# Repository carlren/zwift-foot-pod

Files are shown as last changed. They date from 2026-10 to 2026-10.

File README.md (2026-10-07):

# Carl Foot Pod

A battery-powered foot pod built around the **Seeed XIAO nRF52840 Sense**.
It estimates walking cadence from the on-board gyroscope and publishes it directly
to **Zwift over Bluetooth**. **Foot Pod Lab** on Android previews the six-axis IMU,
records sessions for algorithm development, and reads the pod’s battery voltage
and estimated charge level.

**Firmware:** 0.4.0 · **Android app:** 1.0.1 · **BLE name:** `Carl Foot Pod` · **Software license:** [MIT](LICENSE)

<p>
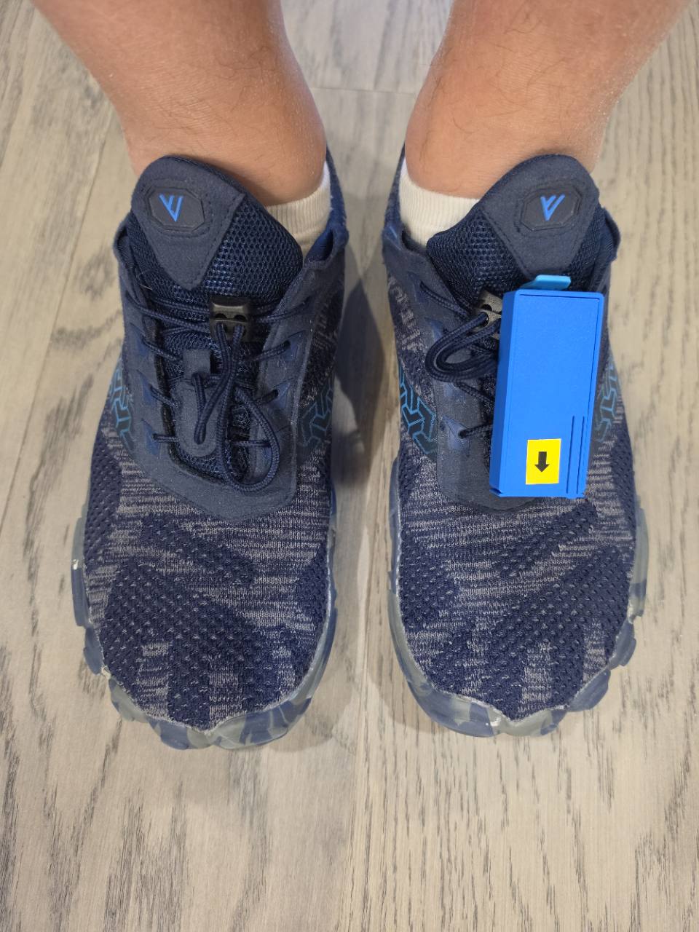
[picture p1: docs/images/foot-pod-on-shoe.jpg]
Blue foot pod case clipped to a shoe’s laces, with its orientation arrow pointing toward the toe
  
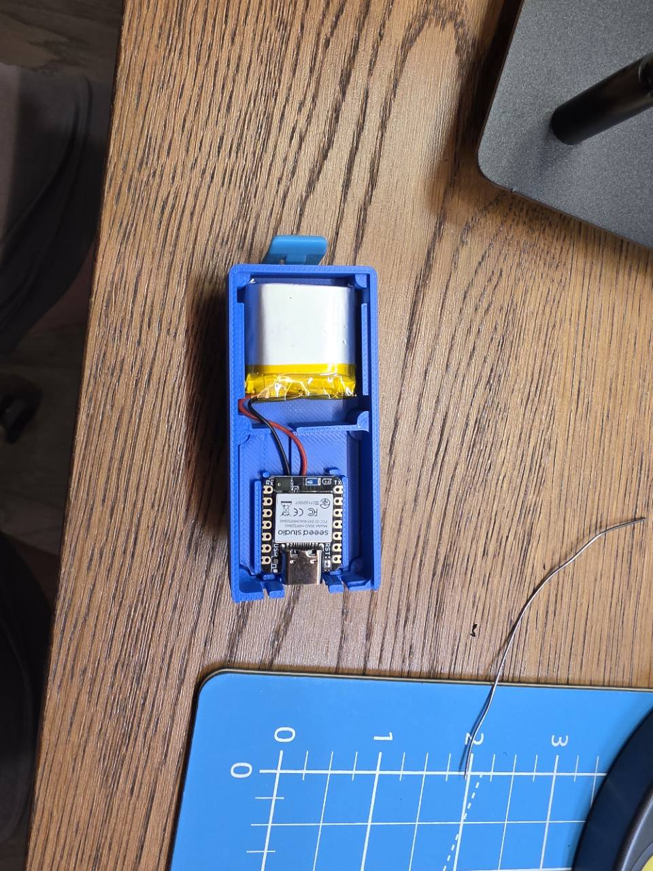
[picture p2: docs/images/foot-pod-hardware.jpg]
Open blue case containing a LiPo pouch battery and the Seeed XIAO board with battery leads attached
  
</p>

The assembled pod clips over the shoelaces. Inside the blue case are the XIAO
board and a pouch battery. The yellow arrow marks the mounting orientation used
for this setup; keep the sensor orientation consistent when comparing recordings.

## Mounting and walking-desk setup

<p>
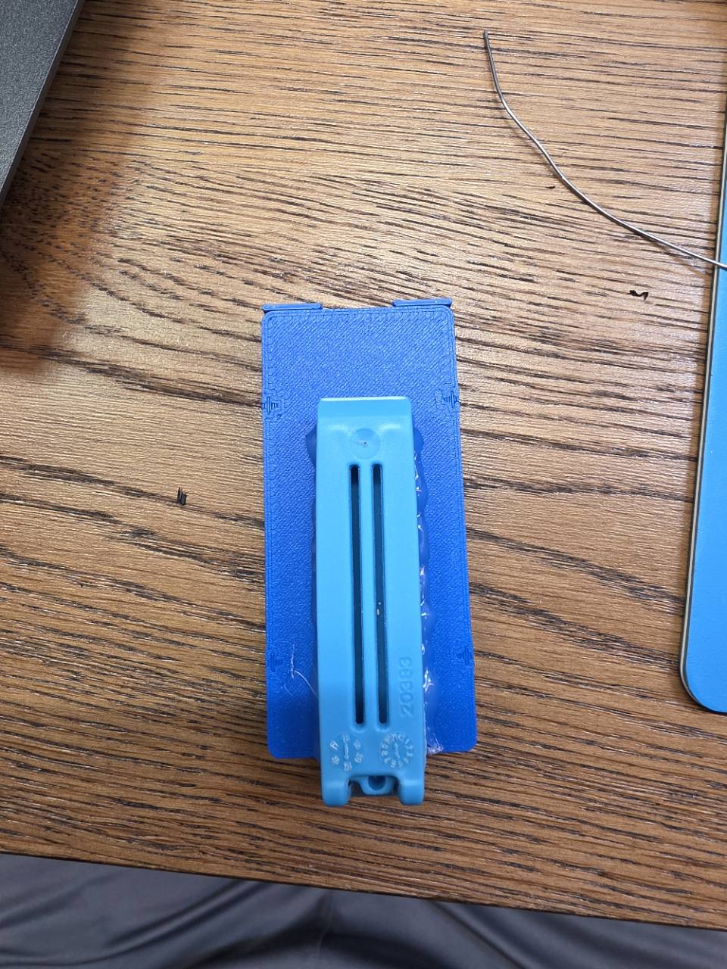
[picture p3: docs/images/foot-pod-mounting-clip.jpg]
Rear of the blue foot pod case showing the long turquoise mounting clip attached to the back
  
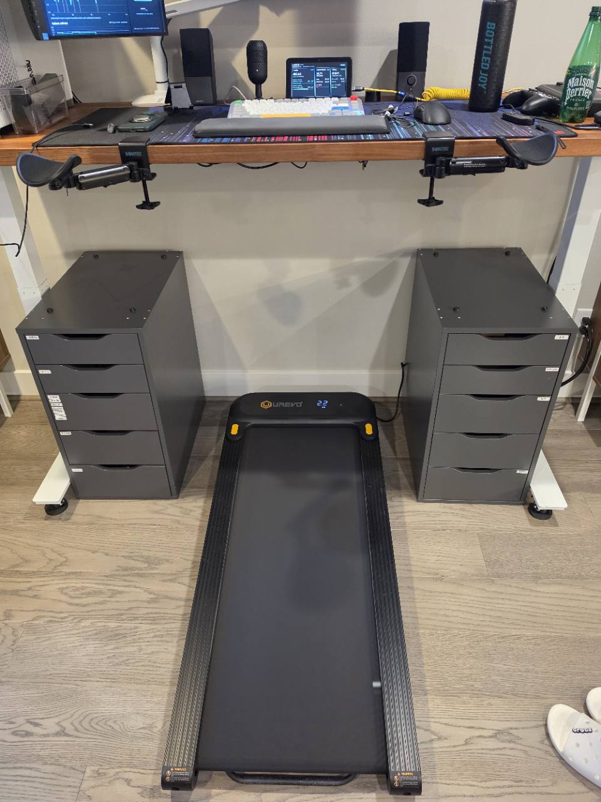
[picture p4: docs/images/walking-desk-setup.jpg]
UREVO walking pad beneath a standing desk with keyboard, displays and front-mounted arm supports
  
</p>

The rear view shows the long mounting clip attached to the case, complementing
the photo of the pod on the shoelaces above. Secure the case so it stays in the
same orientation during walking and recording.

The second photo shows the walking pad under the standing desk, with displays,
a keyboard and arm supports. This is the physical setup used alongside the shoe
pod, Zwift and the phone companion.

The [V5 enclosure design](enclosure/README.md) is now included: printable STLs,
editable STEP/CadQuery files, previews and the original print/assembly guide.
Download the [exact enclosure package](enclosure/low-profile-v5-package.zip) or
browse the [individual parts](enclosure/low-profile-v5/).

## What it does

- Computes cadence on the pod, without a computer or phone relay, and publishes
  Running Speed and Cadence (RSC) notifications once per second.
- Supports two BLE central connections so Zwift and a companion on another device
  can connect. Starting or stopping the companion’s IMU stream leaves cadence publishing active.
- Streams timestamped gyro X/Y/Z and accelerometer X/Y/Z samples at roughly 104 Hz.
- Separates **Connect** for live preview from **Record** for saving a new session.
- Shows battery voltage and an estimated percentage, including a dedicated battery
  bar with charging status and low-battery colors.
- Saves raw IMU data, gyro fit results and reference annotations; retains partial
  captures if recording ends unexpectedly.

Use this pod as a **cadence source**. The speed field required by RSC currently
uses a placeholder 0.70 m step length. Keep the treadmill or another measured
speed source under Zwift’s **RUN SPEED**.

## Parts and purchase links

| Part | Quantity | Purchase / source |
| --- | --- | --- |
| Seeed XIAO nRF52840 Sense | 1 | [Amazon — original board purchase link](https://a.co/d/03LYRqK2) · [Direct listing](https://www.amazon.com/dp/B0DJ6PZGB7) |
| LiPo pouch battery | 1 | The V5 design uses a measured **26.31 × 25.07 × 8.66 mm** cell; the exact purchased battery listing has not been supplied. |
| Housing, sliding cover, board carrier, adapter and lace base | 1 set | [Printable enclosure parts](enclosure/README.md#print-files) · [Complete design ZIP](enclosure/low-profile-v5-package.zip) |
| PLA or PETG filament | As needed | Materials specified in the [print and assembly guide](enclosure/low-profile-v5/PRINT-AND-ASSEMBLE.md#printing). |
| Thin battery mounting tape and CA glue | As needed | The design allows **0.20 mm** tape under the battery and uses CA glue for the adapter; see [assembly instructions](enclosure/low-profile-v5/PRINT-AND-ASSEMBLE.md#assembly-and-use). |

Select the **original Sense model with the on-board IMU** for the firmware and
board carrier in this repository. The Amazon link above is the board link Carl
provided when buying this project's hardware. Battery selection must match the
cell dimensions and clearances in the enclosure design; no unverified battery
product link is presented as the one used here.

## Get the firmware and app

| Component | Download / source |
| --- | --- |
| V5 enclosure | [Original package](enclosure/low-profile-v5-package.zip) · [Design and print guide](enclosure/README.md) |
| Firmware 0.4.0 | [GitHub release, DFU package, HEX and validation](https://github.com/carlren/zwift-foot-pod/releases/tag/v0.4.0) |
| Android app 1.0.1 | [GitHub APK release](https://github.com/carlren/zwift-foot-pod/releases/tag/android-v1.0.1) · [APK on Google Drive](https://drive.google.com/file/d/1NDdZ-bwayQZ8dlKcvDCeHdjqc7yNuZNr/view?usp=drivesdk) |
| Android source and instructions | [android/README.md](android/README.md) |
| Desktop collection, build and protocol details | [Development guide](docs/development.md) |

The repository and its GitHub release downloads are private. The releases are
marked prerelease while broader mounting, gait, runtime and simultaneous-device
stress testing remain unfinished. Firmware 0.3.0 and Android 1.0.0 remain in the
release history.

## Pair with Zwift

1. Power the pod and keep it mounted in the same orientation used for calibration.
2. Open Zwift’s **RUN** pairing screen.
3. Select **Carl Foot Pod** under **CADENCE**.
4. Keep the treadmill or other speed source under **RUN SPEED**.
5. Allow a few walking strides for the cadence estimate to settle. Standing still
   returns cadence to zero after the stop timeout.

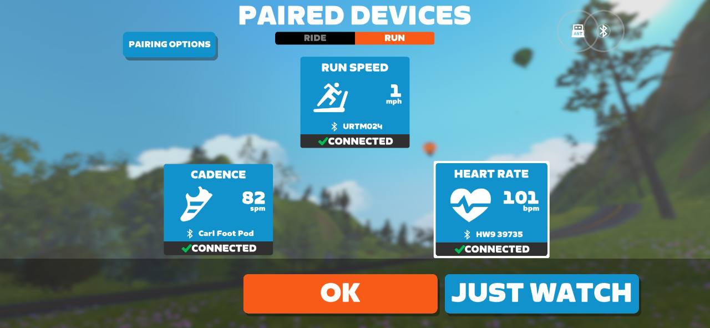
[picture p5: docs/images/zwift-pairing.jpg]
Zwift RUN pairing screen with Carl Foot Pod connected as cadence and URTM024 connected separately as run speed


This user-supplied screenshot shows **Carl Foot Pod connected at 82 steps/min**.
Zwift receives run speed separately from **URTM024**, shown at 1 mph. Heart rate
also comes from a separate device.

## Use Foot Pod Lab on Android

Install the APK on the phone and allow **Nearby devices** permission. Allow
notifications for connection and recording status. Updates install over the
existing app using the same signing key; keep the app installed to retain its
private recordings.

1. Tap **Connect**. Preview starts immediately, with no recording files created.
2. Check the live gyro / acceleration graphs, cadence and packet-gap counter.
3. Choose a label and duration, then tap **Record**. Only new samples are saved.
4. The countdown ends the recording automatically. **Stop recording** saves early
   and keeps preview running; **Disconnect** saves an active recording and releases
   the phone’s connection.
5. For a reference measurement, count steps from **both feet**. After recording,
   enter **Counted steps** and choose **Calculate & save reference**. The app uses
   the actual saved duration rather than forcing the requested timer duration.
6. Choose **Share recording ZIP** and select Drive or another sharing destination.
   Each ZIP contains `imu.csv`, `fit.csv` and `session.json`.

<p>
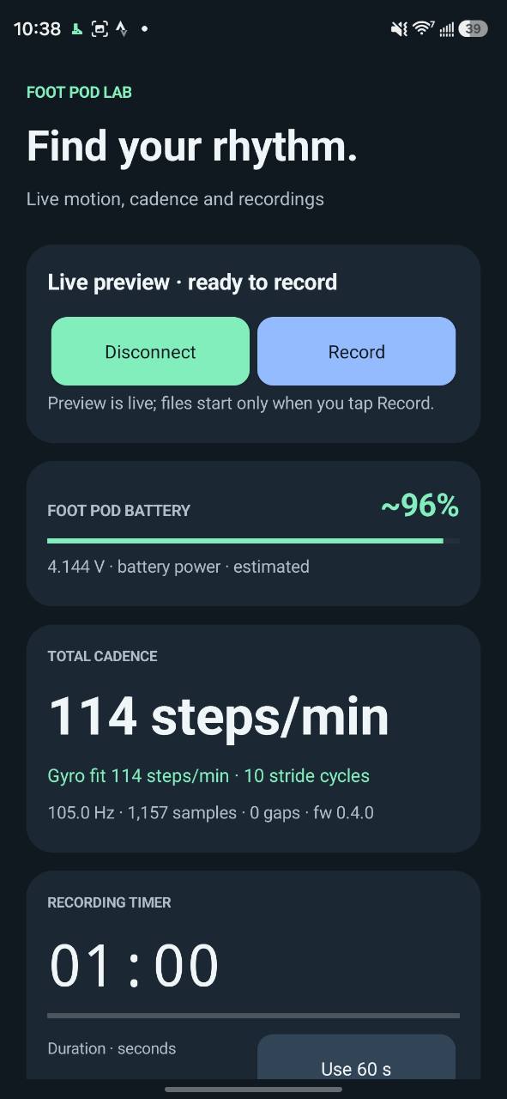
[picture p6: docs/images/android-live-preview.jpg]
Foot Pod Lab live preview on the Galaxy: 114 steps per minute, 105 Hz, zero gaps and a battery bar at approximately 96 percent
  
</p>

The Galaxy S26 Ultra screenshot shows real **live preview** with firmware 0.4.0:

| Displayed reading | Value in the screenshot |
| --- | --- |
| Pod cadence received over RSC | 114 steps/min |
| Local signed-gyro fit | 114 steps/min |
| IMU stream | 105.0 Hz, 1,157 samples, 0 gaps |
| Foot pod battery | 4.144 V, approximately 96%, battery power |
| Recording state | Preview; **Record** is available; duration set to 60 seconds |

The **Foot pod battery** card refers to the pod, not the phone’s battery shown in
Android’s status bar. Its bar is green above 50%, amber at 21–50%, and red at
0–20%. Unavailable readings show “—”; after disconnecting, retained readings are
labeled “last read”. Percentage is interpolated from a typical LiPo voltage curve,
not measured by a calibrated fuel gauge.

The app receives voltage updates every five seconds and battery percentage change
notifications. It uses a connected-device foreground service and a bounded wake
lock during recording. The supplied screenshot demonstrates preview and battery
reads on the Galaxy; it does not demonstrate a completed or screen-locked recording.
Full app behavior and export details are in [the Android guide](android/README.md).

## Workout example

<p>
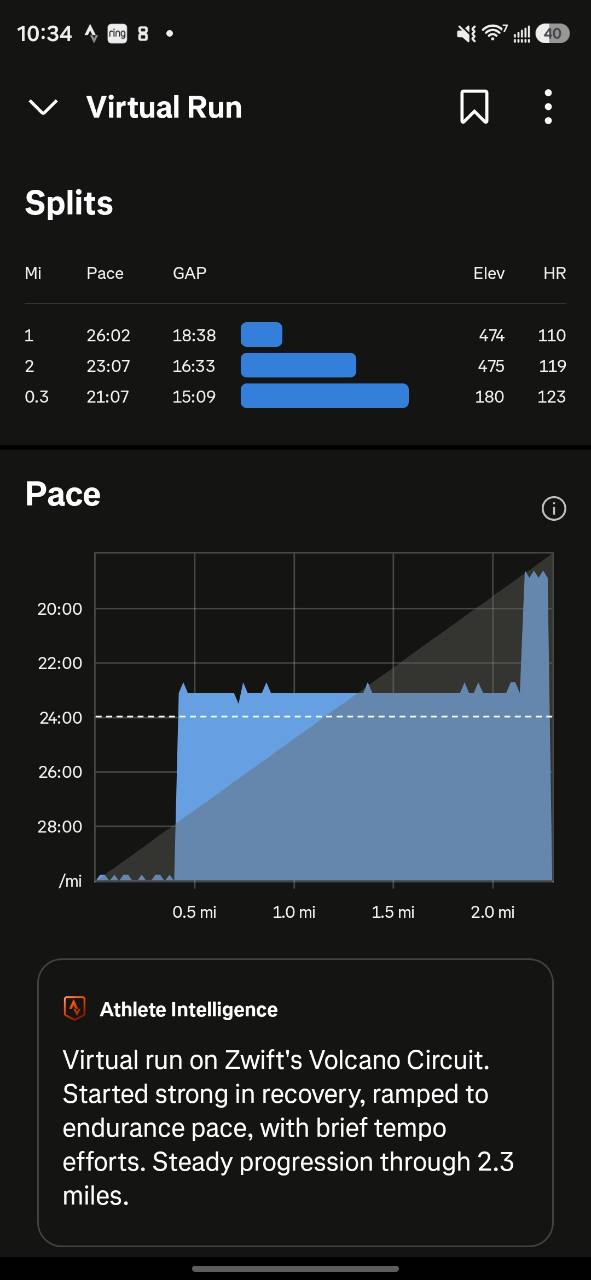
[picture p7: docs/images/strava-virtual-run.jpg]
Strava Virtual Run screenshot showing two one-mile splits and a final 0.3-mile split, plus a pace graph
  
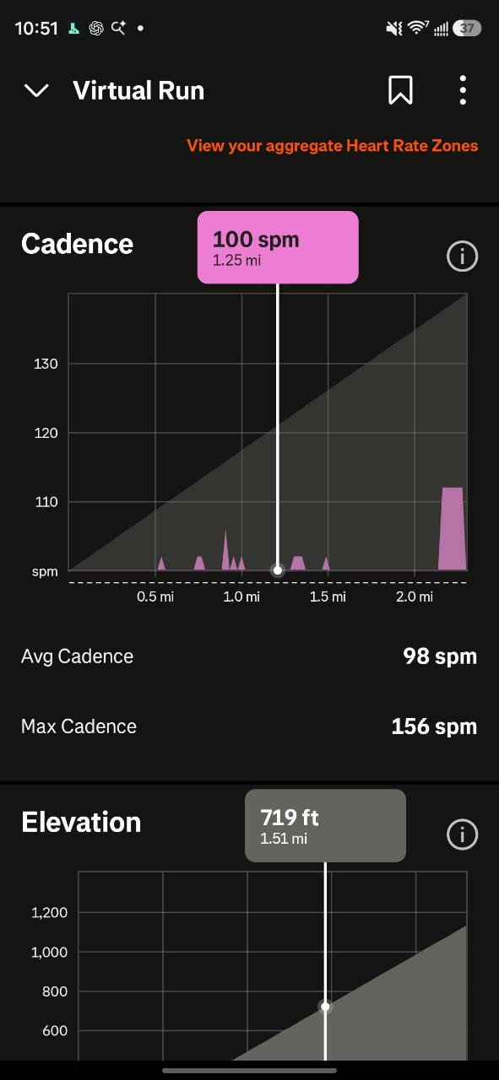
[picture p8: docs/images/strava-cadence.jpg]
Strava Virtual Run cadence graph showing 98 steps per minute average, 156 maximum, and a selected reading of 100 at 1.25 miles
  
</p>

The supplied Strava screenshot shows a **Virtual Run** with two one-mile splits
and a final 0.3-mile split. Pace and heart rate come from the separate sources
shown in Zwift. The screenshots illustrate the workout and live preview; use the
reference recordings below to assess cadence accuracy. The Zwift and phone images
show different cadence readings without synchronized timestamps for comparison.

The additional Strava **Cadence** screenshot shows cadence in the recorded Virtual
Run: **98 spm average**, **156 spm maximum**, and a selected reading of **100 spm
at 1.25 miles**. These are Strava’s displayed activity values; the manual-reference
recordings below provide the separate accuracy checks.

## How cadence is estimated

The primary signal is **signed Y-axis gyroscope rotation**, matching the current
mounting. Acceleration is available for inspection and correlation, but does not
independently trigger cadence.

The detector applies a 40 ms low-pass filter. Rotation below −20 °/s rearms it;
a subsequent crossing of +40 °/s marks a stride cycle. A 450 ms minimum interval
rejects extra cycles. One complete cycle from a pod on one shoe represents **two
total steps**. The estimate is smoothed and returns to zero after three seconds
without a new cycle.

The same detector is implemented in the [firmware](footpod/cadence.h),
[Android app](android/app/src/main/java/com/carlren/footpod/Protocol.java), and
[desktop dashboard](dashboard.py). Desktop axis / threshold edits affect only the
desktop fit; board constants require rebuilding the firmware. The phone currently
uses the same fixed Y-axis settings as the board.

Five saved one-minute walking recordings were replayed through the actual firmware
C++ detector. Reference values were manually supplied by Carl and do not control
the detector’s result:

| Recording | Reference steps/min | Mean firmware steps/min |
| --- | ---: | ---: |
| [Slower walk 1](recordings/20261006T052553_045206Z_walking/session.json) | 70.5 | 70.66 |
| [Slower walk 2](recordings/20261006T052707_444318Z_walking/session.json) | 71 | 70.40 |
| [2 mph walk 1](recordings/20261006T052902_519778Z_walking/session.json) | 92 | 92.06 |
| [2 mph walk 2](recordings/20261006T053044_112366Z_walking/session.json) | 92 | 92.18 |
| [3 mph walk](recordings/20261006T053216_845529Z_walking/session.json) | 110 | 109.98 |

See [firmware replay results](validation/firmware-algorithm-report.json) and
[Android replay results](validation/android-protocol-report.json). These results
cover this mounting and these walking sessions, not every runner, orientation or
pace. Green markers illustrate detected cycles, not validated touchdown times.

## Validation and current limits

The photos and screenshots are supplied by the user; bench and emulator reports
are saved separately under [`validation/`](validation/).

| Evidence | What it establishes |
| --- | --- |
| [Galaxy live screenshot](docs/images/android-live-preview.jpg) | On-phone BLE preview, RSC cadence, matching local gyro fit, battery reads and a displayed 105 Hz stream with zero gaps over 1,157 samples |
| [Zwift pairing screenshot](docs/images/zwift-pairing.jpg) | Carl Foot Pod connected as Zwift cadence, alongside separate speed and heart-rate sources |
| [Strava cadence screenshot](docs/images/strava-cadence.jpg) | Cadence displayed in the Virtual Run activity: 98 spm average, 156 spm maximum, 100 spm at the selected 1.25-mile point |
| [Firmware 0.4.0 bench report](validation/companion-report.json) | 2,093 samples at 104.995 Hz, zero missing packets, 20 concurrent RSC frames, battery reads / notifications, free-slot advertising and reconnect reset on one physical central |
| [Hardware regression report](validation/report.json) | Sensor identity, sampling, RSC packet format, mock-value transport checks, zero-cadence heartbeat and reconnect |
| [Android app checks](validation/android-app-report.json) | Signed APK, emulator installation / launch, decoder / timing checks, native recording files, ZIP sharing and interruption recovery |
| [Battery-bar update checks](validation/android-battery-bar-report.json) | Signed 1.0.1 update installed over 1.0.0, dedicated battery card and unavailable-state display checked in the emulator |

The phone screenshot extends the earlier emulator-only evidence with real Galaxy
preview on battery power. Battery runtime, a sustained simultaneous phone-plus-Zwift
radio test, and Galaxy screen-lock recording still need logged measurements. The
screenshots alone do not establish those results. No recordings are stored on the
board, and lost radio packets cannot be recovered from it.

## Build and develop

Run these commands from the repository root. `rtk` is the command wrapper used in
this workspace; if it is not installed, omit that prefix.

```sh
rtk .venv/bin/python program.py          # build firmware
rtk .venv/bin/python program.py --upload # flash the connected XIAO Sense
rtk python3 android/build.py            # signed Android APK and lint
rtk .venv/bin/python dashboard.py        # desktop live preview at 127.0.0.1:8766
```

The desktop tools use the dependencies in [`requirements.txt`](requirements.txt).
The firmware toolchain is Arduino CLI 1.4.1 with Seeed nRF52 Boards 1.1.13. Android
uses JDK 17, SDK 35, Gradle 8.10.2 and Android plugin 8.7.2. Setup, protocol UUIDs,
ADC details and hardware checks are in [the development guide](docs/development.md).
Android signing and emulator checks are in [the Android guide](android/README.md).

```sh
rtk .venv/bin/python verify_firmware.py # firmware C++ against reference recordings
rtk .venv/bin/python android/check.py  # actual Java decoder, timer and gyro fit
rtk .venv/bin/python test_dashboard.py # desktop preview / recording boundaries
rtk .venv/bin/python test_companion.py # per-client state and battery curve
```

## Repository contents

| Path | Contents |
| --- | --- |
| [`enclosure/`](enclosure/) | Original V5 package, extracted STL/STEP/CadQuery files, previews and assembly instructions |
| [`footpod/`](footpod/) | Firmware, gyro detector, client isolation and battery curve |
| [`android/`](android/) | Android source, Gradle wrapper, signing build script and instrumentation checks |
| [`dashboard.py`](dashboard.py), [`dashboard.html`](dashboard.html) | Desktop live visualization and recording controls |
| [`collect.py`](collect.py), [`replay.py`](replay.py), [`battery.py`](battery.py) | BLE collection, offline gyro replay and battery reads |
| [`recordings/`](recordings/) | All 20 saved local sessions, including five walking references, bench captures and partial / interrupted checks |
| [`validation/`](validation/) | Bench / replay / emulator reports and desktop screenshots |
| [`docs/images/`](docs/images/) | All eight original user-supplied photos / screenshots, copied without editing |
| [`docs/development.md`](docs/development.md) | Detailed desktop, firmware, Bluetooth and build guide |

Session folders include raw data and any saved fits / annotations. Partial and
synthetic or UI-check sessions are retained with their metadata; they are not all
training references. Replay validation selects the five completed recordings
explicitly annotated with `reference_source = user_reported_count`, excluding
sessions marked `exclude_from_training`.

Source, documentation, photos, validation reports and saved recordings are tracked
in Git. Installable firmware and APKs, source archives and checksums are attached
to the GitHub releases. Toolchain downloads, dependencies, caches and local build
outputs are excluded from Git; private Android signing credentials stay outside
the repository.

## Public-release review

The [public-release audit](docs/public-release-audit.md) found no credential leaks
in the scanned history, enclosure or release contents. The repository still
contains personal author metadata, device identifiers, workout data and photos.
Review those personal-data publication choices before making it public.
Project-owned software is now MIT-licensed; vendor components retain their
upstream terms, as described in [the licensing notices](THIRD_PARTY_NOTICES.md).

## License

Project-owned software and associated software documentation are licensed under
[MIT](LICENSE), including commercial reuse, modification and redistribution with
the copyright/license notice retained. [Third-party notices](THIRD_PARTY_NOTICES.md)
identify upstream dependencies and material outside that software license grant.

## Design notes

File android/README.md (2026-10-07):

# Foot Pod Lab for Android

Personal companion app for Carl's XIAO Sense foot pod, firmware **0.4.0 or newer**.
Version **1.0.1**, package `com.carlren.footpod`. Native Java / Android framework,
no runtime third-party libraries, account sign-in or Internet permission. Minimum
Android 12; targets Android 15 and can run on newer Android phones.

## Install and use

Download [Foot-Pod-Lab-1.0.1.apk](https://drive.google.com/file/d/1NDdZ-bwayQZ8dlKcvDCeHdjqc7yNuZNr/view?usp=drivesdk) on the Galaxy,
install it over the existing app to keep recordings, and allow installation from that app if Android prompts. Open **Foot Pod
Lab**, grant **Nearby devices**, and allow notifications for connection / recording
status. Turn on Bluetooth and power the pod. No Android Settings pairing is needed.

1. Tap **Connect**. Live gyro / accelerometer graphs and cadence appear immediately;
   connecting creates no recording files. Battery voltage is refreshed every five
   seconds, while estimated battery percentage also receives change notifications.
   A dedicated **Foot pod battery** card shows a fill bar, estimated percentage,
   voltage and charging state. The bar is green above 50%, amber at 21–50%, red at
   0–20%. Unknown percentage stays “—”; disconnected readings are labeled “last read”.
2. Choose duration (default 60 seconds), label, optional reference steps/min and
   treadmill speed in mph. Tap **Record** only when the preview looks right.
3. The countdown stops recording automatically. **Stop recording** saves early;
   both keep preview running. Recording uses a foreground connected-device service
   and a bounded wake lock to continue when the screen is locked.
4. Count steps from both feet. After recording, enter **Counted steps** and tap
   **Calculate & save reference**. It uses the actual saved device duration. This
   annotates the session; it does not alter the cadence detector.
5. **Share recording ZIP**, then choose Drive (or another sharing target). A ZIP
   contains `imu.csv`, `fit.csv` and `session.json`. Older sessions remain available
   under **Choose recording**. The app does not automatically upload recordings.
6. **Disconnect** releases only the phone's BLE connection and saves any active
   recording. Zwift on a separate device can remain connected to the pod.

Both graphs show the latest 20 seconds. Cyan / amber / violet are X / Y / Z; the
gyro graph also shows filtered Y in white and estimated stride markers in green.
The cadence headline comes from the pod's RSC stream; the app's **Gyro fit** runs
the same signed Y-axis detector for comparison. The app does not change firmware
mode or calibration constants. Acceleration is shown as a secondary signal.
Battery percentage is a voltage-based estimate, particularly under load / charge.

Raw data stay in private app storage. Stopping, losing Bluetooth, or encountering
bad packets preserves partial recordings and marks failures in metadata. Writes
are flushed and checkpointed roughly every second; force-stopping the app can
lose data still in memory. Reopening retains the raw files and marks interrupted
sessions incomplete. Uninstalling the app removes its recordings: share wanted
sessions first. No samples are stored on the board.

## Build

This computer has JDK 17 at `/home/carlren/android-dev/jdk-17` and Android SDK at
`/home/carlren/android-dev/android-sdk`. The Gradle wrapper pins 8.10.2 and the
Android plugin pins 8.7.2. Compile SDK / build tools are 35.

```sh
rtk python3 android/build.py
```

The build script accepts `JAVA_HOME` / `ANDROID_HOME` on another computer. It
builds the release, runs Android lint, verifies its APK signature, and copies it
to `android/dist/Foot-Pod-Lab-1.0.1.apk` with a SHA-256 checksum. Its persistent
personal signing key and password are outside this repository in
`~/.local/share/foot-pod-lab/`, with restricted permissions. Preserve those files
privately to sign future updates; never upload or commit them. Only the APK is
distributed. Generated APKs, caches and machine paths are ignored by Git.

## Checks and limitations

```sh
rtk .venv/bin/python android/check.py
```

This compiles the exact Java protocol / detector / recording-window code on the
host, checks malformed packets, signed raw values, unsigned sequence/time wraps,
packet gaps, record boundaries, countdown, reference calculation, synthetic cadence
and stop timeout. It replays all five original walking recordings and checks every
stride decision and fit against the validated desktop detector; the raw reference
recordings are included in this repository. Evidence is in
`validation/android-protocol-report.json`.

`app/src/androidTest/.../TestProbe.java` is a dependency-free Android instrumentation
check for the actual CSV / fit / metadata writer, reference annotation, ZIP export,
read-only sharing provider, traversal rejection, partial sessions and interrupted
session recovery. Synthetic inputs occur only in this test APK, never in the
delivered application. To run on a disposable emulator using debug builds:

```sh
rtk ./gradlew assembleDebug assembleDebugAndroidTest
rtk adb -s EMULATOR_SERIAL install -r app/build/outputs/apk/debug/app-debug.apk
rtk adb -s EMULATOR_SERIAL install -r app/build/outputs/apk/androidTest/debug/app-debug-androidTest.apk
rtk adb -s EMULATOR_SERIAL shell am instrument -w com.carlren.footpod.test/com.carlren.footpod.TestProbe
```

Do not replace a release installation containing wanted recordings with a debug
build: the signing keys differ. The supplied APK was signature-verified, installed,
launched and visually checked in an Android 15 emulator. Native Android storage
checks passed there. The [user-supplied Galaxy screenshot](../docs/images/android-live-preview.jpg)
now shows live BLE preview on the physical phone: 114 steps/min, 105.0 Hz, 1,157
samples with zero displayed gaps, and battery power at 4.144 V / approximately 96%.
It does not establish screen-lock recording, battery runtime or a sustained test
of two physical phone-plus-Zwift radio links. Firmware 0.4.0's prior bench check
exercised concurrent cadence / raw IMU / battery data using one computer central.

Android implementation follows the official guidance for
[BLE permissions](https://developer.android.com/develop/connectivity/bluetooth/bt-permissions),
[background BLE connections](https://developer.android.com/develop/connectivity/bluetooth/ble/background),
and [edge-to-edge window insets](https://developer.android.com/develop/ui/views/layout/edge-to-edge).

## License

The project-owned Android application is [MIT-licensed](../LICENSE).
See [upstream notices and license scope](../THIRD_PARTY_NOTICES.md).

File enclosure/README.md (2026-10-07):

# Low-profile V5 enclosure

Imported from the user-supplied [Drive package](https://drive.google.com/file/d/1o0rKppdrjITLiIJF9fO0QQAxFphHp7R-/view?usp=drivesdk).
The original ZIP and every extracted file are preserved without edits.

- [Download the original package](low-profile-v5-package.zip)
- [Print and assembly instructions](low-profile-v5/PRINT-AND-ASSEMBLE.md)
- [Editable STEP assembly](low-profile-v5/low-profile-v5.step)
- [Parametric CadQuery source](low-profile-v5/design.py)
- [Combined print plate](low-profile-v5/low-profile-v5-print-plate.stl)
- [Packaged CAD validation](low-profile-v5/validation.json)
- [File checksums](SHA256SUMS.txt)

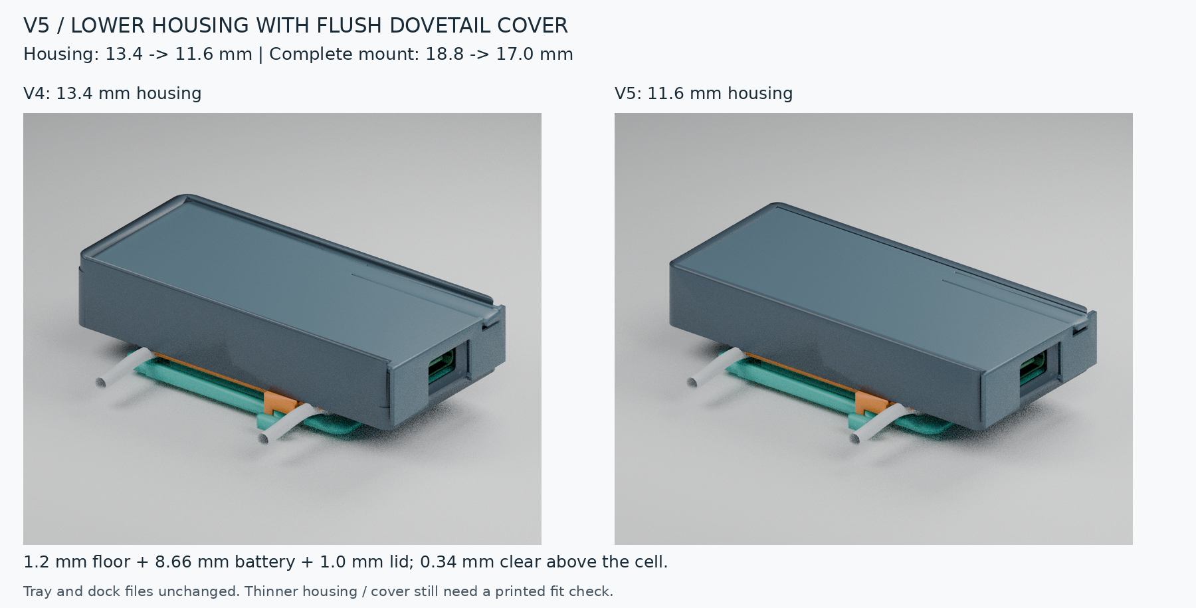
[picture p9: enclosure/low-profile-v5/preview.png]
V5 enclosure preview


## Print files

| Part | STL |
| --- | --- |
| Housing | [body.stl](low-profile-v5/body.stl) |
| Sliding cover | [sliding-cover.stl](low-profile-v5/sliding-cover.stl) |
| Board carrier | [board-carrier.stl](low-profile-v5/board-carrier.stl) |
| Glue-on adapter | [glue-on-adapter.stl](low-profile-v5/glue-on-adapter.stl) |
| Lace-mounted base | [lace-base.stl](low-profile-v5/lace-base.stl) |

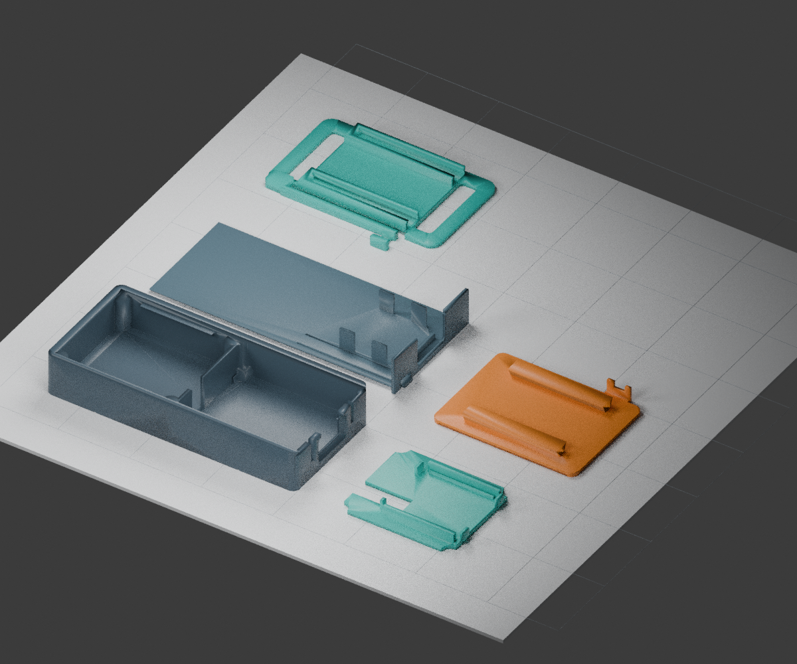
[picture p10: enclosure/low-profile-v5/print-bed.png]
Parts arranged on the print bed


The packaged design specifies a **70 × 32 × 11.6 mm** housing and a roughly
**72 × 36 × 17 mm** mounted assembly. It was designed around a measured
**26.31 × 25.07 × 8.66 mm** battery. Those dimensions and validation statements
come from the supplied CAD package; importing it did not rerun CAD generation or
physical print tests. Follow the original assembly instructions, particularly the
small battery clearance and keeping glue out of the release mechanism.

`design.py` uses CadQuery and trimesh. `render.py` runs in Blender after the geometry
is generated. The `references/` directory retains the fitted reference STLs and
the supplied Seeed XIAO board STEP reference used by the source.

## Provenance and licensing

The imported ZIP's SHA-256 is:

```text
71ce6ecec9b5c4e8727a5d5ef1691460e8cd4ec3a0ffebbe1df0ce8545094290
```

Its bytes were checked against the authenticated Drive response. The original
archive contains 17 files; the extracted copies also match the archive exactly.

The package includes `references/sense-official-XIAO-nRF52840 v15.step`, a
third-party board reference. Seeed provides an official Sense 3D model through
[its board documentation](https://wiki.seeedstudio.com/XIAO_BLE/). The supplied
package and STEP header do not state redistribution terms. Confirm those terms
for that reference or the ZIP that contains it. The project’s MIT license covers
our original Python CAD generation/render software, and does not relicense this
board reference or the STL/STEP assets. See [license scope and notices](../THIRD_PARTY_NOTICES.md).

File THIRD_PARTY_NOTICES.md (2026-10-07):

# License scope and upstream notices

The [MIT license](LICENSE) covers project-owned software and its associated
software documentation: the firmware application and gyro detector, Android app,
desktop dashboard/collector, development/check scripts, and original Python CAD
generation/render scripts. Copyright (c) 2026 Carl Yuheng Ren.

Third-party components retain their own licenses. The root MIT license does not
relicense the board/SDK, vendor CAD, or upstream material. Photos, workout datasets
and STL/STEP assets are outside this software license grant.

## Components used by the software

| Component | Use | Upstream licensing |
| --- | --- | --- |
| Seeed nRF52 Boards 1.1.13 / Arduino-Adafruit core | Board startup, GPIO, ADC, USB and runtime | Core license is LGPL-2.1-or-later; individual bundled files/libraries have their own notices. [Source](https://github.com/Seeed-Studio/Adafruit_nRF52_Arduino). |
| Adafruit Bluefruit52Lib | BLE peripheral services and connections | MIT; Copyright (c) 2016 Adafruit Industries. [License copy](LICENSES/Adafruit-Bluefruit-MIT.txt). |
| Adafruit TinyUSB Arduino | USB serial support | MIT; Copyright (c) 2019 Ha Thach for Adafruit Industries. [License copy](LICENSES/Adafruit-TinyUSB-MIT.txt). |
| Nordic nrfx TWIM driver | Internal IMU I²C bus | BSD-3-Clause; Copyright (c) 2015–2020 Nordic Semiconductor ASA. [License copy](LICENSES/Nordic-nrfx-BSD-3-Clause.txt). |
| Nordic SoftDevice S140 API | BLE stack API on the nRF52840 | Nordic's supplied license, including its Nordic-chip usage condition. [API header notice](LICENSES/Nordic-SoftDevice-API.txt). This project does not relicense the SoftDevice. |
| Gradle wrapper | Android build launcher | Apache-2.0; existing notices remain in `gradlew`, `gradlew.bat` and the wrapper JAR. [License copy](LICENSES/Apache-2.0.txt). |
| Zephyr default LiPo OCV table | Battery-percent voltage breakpoints | Apache-2.0; Copyright 2024 Embeint Inc. [Upstream table](https://github.com/zephyrproject-rtos/zephyr/blob/main/include/zephyr/dt-bindings/battery/battery.h). |

The battery table's microvolt values were rounded to millivolts in
`footpod/companion.h`; the interpolation code is project-owned. The source table
is based on Analog Devices Application Note 4189, Table 1. Its Apache-2.0
attribution and [license text](LICENSES/Apache-2.0.txt) are retained here.

The board core/libraries are installed by the build toolchain; their sources have
not been modified in this project. `footpod/imu_bus.c` includes the installed
Nordic driver so it is compiled into the application. Thus the firmware does use
vendor software, even though we wrote the application/algorithm ourselves. Keep
the pinned SDK's upstream notices and applicable source/relinking terms with
firmware distributions; this document is not a complete SDK bill of materials.

## Enclosure board reference

`enclosure/low-profile-v5/references/sense-official-XIAO-nRF52840 v15.step` is an
unchanged, third-party board shape used for enclosure fit checks. The same file is
inside the original enclosure ZIP. It is not Seeed firmware code and is not
covered by the project MIT license. See the [enclosure provenance](enclosure/README.md#provenance-and-licensing)
for its source and the supplied package's licensing information.

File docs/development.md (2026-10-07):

# Development and protocol guide

Return to the [illustrated project README](../README.md). Run the commands below
from the repository root. The desktop dashboard, firmware, protocol, replay tools
and validation reports are described here.

## Live visualization app

```sh
rtk .venv/bin/python dashboard.py
```

Open **http://127.0.0.1:8766** on this computer. Click **Connect** to see a live
preview immediately. Preview creates no recording files. When the samples look
right, choose an activity label, duration, shoe side and optional reference cadence,
then click **Record**. Only newly received samples are saved, with session timestamps
starting at zero. **Stop recording**, or the duration timer, saves the session and
keeps the live preview running. You can record another session on the same Bluetooth
connection. **Disconnect** releases the pod and saves any active recording first.
Firmware 0.4.0 allows Zwift on another device to stay connected while you preview or record here.
Two apps on the same operating system may share a single physical BLE connection;
use a separate phone or computer for independent companion controls.

The recording timer shows a large countdown, elapsed seconds and a progress bar.
Click **Use 60 seconds** for a one-minute manual cadence count. Count steps from
**both feet** during that recording. After it ends, enter the total in **Counted
steps** and click **Calculate & save reference**. The app calculates
`steps × 60 / actual elapsed seconds` and saves both the count and reference cadence
in that recording's `session.json`. If you stop early, its actual elapsed time is
used. If you count only one foot, double your count before entering it. Alternatively,
enter a known steps/min value in the reference field and click **Save typed steps/min**.
The latest saved recording remains available for annotation after restarting the app.

The server uses Python's standard library and the existing BLE recorder; no new
dependencies or firmware update are needed. It only listens on this computer.

The dashboard shows all six IMU axes, filtered gyro rotation, stride-cycle markers,
estimated total steps/min, optional reference cadence, sample rate and packet gaps.
The shoe animation and normalized curve illustrate the **estimated one-foot rhythm**,
not reconstructed foot position. Battery voltage, estimated percentage and charger status are read at
connection time; they are not continuously refreshed during the high-rate stream.

The dashboard fit is a **signed gyroscope cycle prototype**. Y rotation is the
primary default axis for the current shoe mounting; X/Y/Z is selectable. A 40 ms
low-pass filter removes jitter. A negative rearm (default -20 °/s) followed by a
positive crossing (default 40 °/s) detects one cycle per one-foot stride, with a
450 ms minimum interval and a 3 second stop timeout. Total cadence is twice the
one-foot cycle rate. Acceleration remains a secondary signal for correlation and
impact inspection; it cannot independently trigger cadence. Cycle markers are
not validated touchdown times. The shoe animation illustrates cycle timing.

This is not a broadly validated gait algorithm. Unchanged defaults replayed five
one-minute recordings within the user's references: about 70–71 steps/min at the
slower pace 92 steps/min at 2 mph, and 110 steps/min at 3 mph. Results are in
`validation/gyro-reference-report.json`. Firmware 0.4.0 runs the same Y-gyro detector directly on the board.
Dashboard axis / threshold edits affect the computer estimator only; board constants
are defined in `footpod/cadence.h` and require reflashing to change. Live settings reset the detector and apply to
subsequent samples, while raw recording continues. Replace `Detector.update()` in
`dashboard.py` as the algorithm is developed.

All raw samples remain in `imu.csv` and `session.json`. The dashboard also saves
`fit.csv` with every sample's selected gyro axis, raw / filtered angular velocity,
acceleration magnitude, stride-cycle decision, cadence, phase, and detector settings, plus `fit-settings.json` with configuration changes.
Download the raw data, fit, and session details through the links in the app.
The display shows the latest 20 seconds, updating five times per second; recording
keeps every received sample. If the connection fails, partial files are retained
and the app reports the error. Click **Connect** to reconnect and preview, then **Record** when ready.

```sh
rtk .venv/bin/python test_dashboard.py
```

This verifies cadence on synthetic 70/109/180 spm gyro signals, the stop timeout, extra-strike
rejection, request validation, timestamp wrapping, file-free preview, recording
boundaries, live snapshots, repeat recording and fit CSV output. The browser and
real-pod integration check is recorded in `validation/dashboard-report.json`.

## Replay recordings through the gyro detector

```sh
rtk .venv/bin/python replay.py recordings/SESSION_FOLDER --axis y
```

This writes `gyro_fit.csv` and `gyro-summary.json` alongside a saved session,
without overwriting its original `fit.csv`. The mean / median cadence exclude
five seconds of estimator warm-up. Reference values come from `session.json`;
the reference does not control the detector or force its estimates. The original
speed text is preserved when the unit is uncertain.

## Standalone Zwift use

Firmware 0.4.0 computes cadence on the board from signed Y-axis rotation. On battery
power, no computer or dashboard is required. In Zwift **RUN → CADENCE**, select
**Carl Foot Pod**, keeping your existing treadmill / speed source under **RUN SPEED**.
Keep the pod mounted in the same case orientation used for the reference recordings.
Allow a few seconds of walking for the first cadence estimate. Zero-cadence
heartbeats continue while standing still. Zwift and a companion can connect together: two physical Bluetooth clients are
supported, with independent subscriptions and capture controls. Recording never
pauses the cadence heartbeat; stopping or disconnecting the companion leaves Zwift connected.

The exact C++ code used on the board is also compiled and replayed on the computer:

```sh
rtk .venv/bin/python verify_firmware.py
```

This check requires `g++` and the local reference recordings. It checks synthetic
70/92/110/180 spm signals, timer rollover, stop behavior, and every gyro-cycle decision
against the dashboard on the saved walking sessions. Evidence is in
`validation/firmware-algorithm-report.json`. Battery diagnostics and raw IMU collection
remain available. `mock` commands are temporary transport tests; boot defaults to
actual gyro cadence.

## Read battery voltage and estimated percentage

```sh
rtk .venv/bin/python battery.py
```

This reads five measurements over Bluetooth and saves `validation/battery-report.json`.
The board also includes `battery_mv`, `battery_pct`, `charging`, and `usb_power` in USB telemetry.
Voltage is sampled once per second from AIN7 / P0.31, with the battery divider enabled
by keeping P0.14 LOW. The 12-bit ADC uses the internal 3.0 V reference, a 40 µs sample
time, and 4× oversampling. The schematic's 1 MΩ / 510 kΩ divider gives:
`battery_mV = round(adc_count * 3000 / 4096 * 1510 / 510)`.
Voltage is uncalibrated. Percentage is a piecewise interpolation of a typical LiPo
open-circuit curve (Zephyr's default, based on Analog Devices AN4189 Table 1).
It clamps to 0–100%; it is an estimate, particularly under charge or load, not a
fuel-gauge measurement. The curve can be calibrated in `footpod/companion.h`.
Standard Battery Service `180F` / Battery Level `2A19` exposes one unsigned byte
(0–100), readable at any time and notified when the percentage changes.
The charger output on P0.17 is active LOW; USB power presence comes from VBUSDETECT.
Charger-current settings are unchanged.

The read-only characteristic `e85b0005-6d10-4a22-90c5-c813f72b1357` is in the existing
collection service. Its six bytes are `<HHBB`: battery millivolts, raw ADC count,
charger-active flag (0/1), and USB-present flag (0/1). The existing IMU data and
status formats are unchanged. The [Galaxy screenshot](images/android-live-preview.jpg)
shows 4.144 V and battery power with no USB present. Battery runtime remains unmeasured.

## Record IMU data on battery

The board boots in normal cadence mode. The computer's recorder starts and stops
collection over Bluetooth, with no USB commands needed. RSC publishing continues
during collection. Both clients can subscribe to cadence, and either can independently
start or stop its own raw IMU stream. Disconnect clears only that client’s capture state.
Keep this computer within Bluetooth range of the shoe.

From a terminal on this computer:

```sh
cd /home/carlren/Documents/zwift-foot-pod-firmware
rtk .venv/bin/python collect.py --seconds 15 --label stationary
rtk .venv/bin/python collect.py --seconds 90 --label walking --foot left
rtk .venv/bin/python collect.py --seconds 90 --label running --foot left
```

Add `--speed-kph 5` for a known treadmill speed, or `--reference-spm 109` for a known
total step rate. These are annotations, not pod measurements. A reference step count
or video is useful for checking the future algorithm against actual foot strikes.
Use a new recording label for each speed, mounting position, or activity. Keep the
pod secured in the same orientation on the shoe during each recording.

Each session creates a new folder under `recordings/` containing:

- `imu.csv`: all received samples at approximately 104 Hz, with sequence numbers,
  device microseconds, unwrapped session time, host receive timestamps, raw gyro /
  accelerometer values, and converted degrees/second / g values.
- `session.json`: activity label, shoe side, optional reference cadence / speed,
  firmware version, sample rate, packet gaps, saturation counts, sensor errors,
  and whether the recording finished successfully.

Ctrl+C stops early and retains the partial recording. Radio disconnection, stalled
data, malformed packets, or a device reset end the capture and preserve an error
in the session file; run the recorder again for a fresh session. Bluetooth
notifications are not guaranteed delivery. The pod keeps sampling during congestion
and the recorder counts gaps. Acquisition timestamps, rather than host arrival times,
are the timing reference for algorithm development. No samples are stored on the pod;
data outside computer radio range cannot be recovered.

The BLE protocol has service `e85b0001-6d10-4a22-90c5-c813f72b1357`, data / control /
status UUIDs with suffix numbers `0002`, `0003`, `0004` in the same base. A data packet
is 20 bytes, `<II6h`: sample sequence, device microseconds, gyro X/Y/Z, accel X/Y/Z.
Both counters are unsigned 32-bit and wrap. Scale factors remain 0.035 degrees/second
and 0.000244 g per count. Write byte `01` to control to start, `00` to stop; subscribe
to data first. The 16-byte status is `<BBBBIII`: version=1, flags (IMU ready=1,
collection enabled=2, data subscribed=4), sensor identity, reserved=0, cumulative
sent packets, rejected packets, and sensor read errors. Capture flags and sent /
rejected counts are per connection, reset on reconnect; sensor read errors are global.

```sh
rtk .venv/bin/python validate_collection.py # 20-second Bluetooth-only hardware check
```

This also verifies CSV output and return to cadence mode after disconnect/reconnect.
Evidence is saved to `validation/collection-report.json`. USB can provide power for
the bench check; the collector never opens the USB serial port.

## Companion phone protocol and validation

A BLE app can connect as the second central while Zwift receives cadence. Read
Battery Level `2A19` for the estimated percent and custom characteristic `0005`
for millivolts and charger / USB flags. For raw IMU recording, subscribe to `0002`,
then write **hex byte** `01` (not ASCII “01”) with response to `0003`. Write `00`
to stop. Subscribe / preview and saving to files are separate app responsibilities.
The firmware sends timestamped packets; the phone app must decode and save them.
The [Android companion](../android/README.md) implements this protocol and saves
sessions on the phone. No recording storage is provided on the board.
Controls do not change the shared cadence algorithm, and read/write access is open
without pairing. Disconnect the companion when finished to free its slot.

```sh
rtk .venv/bin/python test_companion.py      # actual C++ client state + battery curve
rtk .venv/bin/python validate_companion.py  # actual BLE concurrency, battery reads, advertising
```

The hardware check uses one physical central subscribed to both RSC and IMU,
reads battery / status during capture, checks cadence gaps, confirms advertising
while connected, and checks stop and reconnect. The 0.4.0 bench run received 2,093 IMU samples at 104.995 Hz with zero missing
packets while receiving 20 cadence frames; the maximum cadence gap was 1.077 s.
It read voltage and percentage five times during capture and received 16 battery
notifications. No I²C errors occurred. Its report explicitly records
that two separate radio links require a separate phone test. It does not simulate
a second physical central using two clients on the same Bluetooth adapter.

## Current behavior

- Reads the LSM6DS3TR-C accelerometer and gyro at 104 Hz over the internal I²C bus.
  Acceleration is in g (±8 g), angular velocity in degrees/second (±1000 dps).
- Checks sensor identity and configuration, reads only fresh data, and stops reporting
  cadence when sensor data is stale. I²C has a 50 ms timeout; a stalled sensor cannot
  block Bluetooth indefinitely. Reboot to recover after a bus timeout.
- The on-board detector uses signed Y-axis gyroscope rotation, a 40 ms low-pass filter, +40 °/s detection / -20 °/s rearm,
  a 450 ms minimum stride interval, smoothing, and a 3 second stop timeout. It assumes
  one pod on one shoe and doubles the detected foot-strike rate to get total steps/min.
  It was checked against five one-minute walking recordings at the three reported
  paces. Cadence starts after two detected cycles and returns to zero after stopping.
  Broader gait / mounting validation is still limited to the current shoe setup.
- Publishes a four-byte Running Speed and Cadence measurement once per second,
  including zero cadence while idle. It advertises continuously and automatically
  advertises again after disconnection. Two Bluetooth clients are supported at a time; it keeps advertising while a slot is free.
- Starts without waiting for a USB serial connection. USB prints JSON telemetry at
  5 Hz while a serial host is connected and reading. A stalled reader can lose
  telemetry updates but cannot pause the IMU or Bluetooth. The red LED indicates
  failed IMU startup.

## Bluetooth format

| Item | UUID / value |
| --- | --- |
| Advertised service | RSC `1814` |
| RSC Measurement (notify + CCCD) | `2A53` |
| RSC Feature (read) | `2A54`, value `0000` (no optional features) |
| Sensor Location (read) | `2A5D`, value `06` (left foot) |
| Device information | `180A`, software revision `0.4.0` |
| Battery level (read + notify) | `180F` / `2A19`, estimated percentage 0–100 |
| Battery diagnostics (read) | `e85b0005-6d10-4a22-90c5-c813f72b1357`, `<HHBB` |
| Appearance | `0441` (running/walking sensor in shoe) |

Measurement: `[flags=0, speed_low, speed_high, cadence_spm]`.
Speed is an unsigned little-endian integer in units of 1/256 m/s. For now it is
`cadence * 0.70 meters / 60 seconds`; this is mock speed, not measured speed.
Only the mandatory fields are sent; stride length, distance, running-status detection,
and calibration control are not claimed.

In Zwift's **RUN** pairing screen, try **Carl Foot Pod** under **CADENCE** and keep
your existing treadmill/speed source under **RUN SPEED**. Selecting this pod for
speed uses the placeholder speed estimate. Our Bluetooth validator disconnects at
the end so the pod is available for Zwift.

## USB commands

Open the board's serial port at 115200 baud and send a newline after each command:

| Command | Effect |
| --- | --- |
| `imu` | Return to the live gyro detector and reset its cadence estimate |
| `mock 109` | Publish fixed 109 steps/min; IMU sampling continues |
| `mock 180` | Publish fixed 180 steps/min |
| `stop` | Clear fixed mode and reset the detector; new motion can trigger cadence again |

Fixed cadence accepts 1–255. Commands are temporary; reboot always starts IMU mode.
The constants in `footpod/cadence.h` are the gyro calibration knobs.
Change `GyroCadence.update()` when refining the on-board algorithm. `validation/imu.jsonl`
contains a stationary capture; raw gyro and acceleration remain available
through serial for walking/running data collection.

## Build, flash, and validate

Installed locally: Arduino CLI 1.4.1, Seeed nRF52 Boards 1.1.13, and `.venv`
dependencies pinned in `requirements.txt`. Bluefruit and the Nordic I²C driver are
provided by the board package. No board-package files were edited.

```sh
cd /home/carlren/Documents/zwift-foot-pod-firmware
rtk .venv/bin/python program.py          # compile only
rtk .venv/bin/python program.py --upload # compile and flash application
rtk .venv/bin/python validate.py         # USB + real Bluetooth hardware checks
```

`program.py` enables the bundled Nordic TWIM driver using build flags. The small
`imu_bus.c` file builds the vendor source that Seeed otherwise omits from `core.a`.
The IMU supply GPIO uses high drive, matching Seeed's own IMU library. `program.py`
only grants temporary serial-node access with `sudo -n setfacl` if needed; it does
not change global device permissions or group membership. Close serial monitors
before programming. If automatic bootloader entry fails, double tap RESET and retry.
The existing bootloader is retained. Compiled artifacts are in `build/`.

`validate.py` expects a stationary board and checks sensor identity, sample rate,
gravity, zero I²C errors, RSC discovery/metadata/CCCD, exact packets at 109/180/255
steps/min, rejected out-of-range input, zero heartbeat with the serial host closed,
and disconnect/reconnect. It leaves the board in IMU mode and saves evidence in
`validation/report.json`, `validation/imu.jsonl`, and `validation/ble.jsonl`.
Closing the serial session tests independence from the USB host, not battery power.

For a fresh toolchain, obtain Arduino CLI from Arduino's official downloads, place it
at `tools/arduino-cli`, then run:

```sh
rtk tools/arduino-cli core update-index --additional-urls https://files.seeedstudio.com/arduino/package_seeeduino_boards_index.json
rtk tools/arduino-cli core install Seeeduino:nrf52@1.1.13 --additional-urls https://files.seeedstudio.com/arduino/package_seeeduino_boards_index.json
rtk python3 -m venv .venv
rtk .venv/bin/pip install -r requirements.txt
```

## References

- [Seeed board documentation](https://wiki.seeedstudio.com/XIAO_BLE/)
- [Seeed battery-divider schematic](https://files.seeedstudio.com/wiki/XIAO-BLE/Seeed_Studio_XIAO_nRF52840_PDF.pdf)
- [Seeed IMU library (including the high-drive supply configuration)](https://github.com/Seeed-Studio/Seeed_Arduino_LSM6DS3/blob/master/LSM6DS3.cpp)
- [ST LSM6DS3TR-C datasheet](https://www.st.com/resource/en/datasheet/lsm6ds3tr-c.pdf)
- [Bluetooth Running Speed and Cadence service](https://www.bluetooth.com/specifications/specs/running-speed-and-cadence-service/)
- [Zwift running device pairing](https://support.zwift.com/de/-ry2NdSw9B)
- [Bleak Bluetooth client API](https://bleak.readthedocs.io/en/latest/api/client.html)

- [Zephyr typical LiPo voltage curve](https://github.com/zephyrproject-rtos/zephyr/blob/main/include/zephyr/dt-bindings/battery/battery.h)

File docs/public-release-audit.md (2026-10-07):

# Public-release audit

Audit date: **2026-10-07**. Repository visibility remains **private**.

## Result

No credential leaks were detected in the scanned repository history, enclosure
package, or downloaded release contents. Publication would nevertheless expose
personal information already present in the project. Choose whether to retain
that information before changing visibility; the repository is not anonymous.
Licensing update after this audit: the project-owned software now has an MIT
license. Upstream components and the third-party board CAD reference remain
under their own terms; see [license scope and notices](../THIRD_PARTY_NOTICES.md).

## Scope and checks

- Fetched the repository's remote tags and inspected all reachable Git history:
  12 commits before the enclosure/audit addition, through `e53d79d`.
- Ran checksum-verified **Gitleaks 8.30.1**, with redacted JSON reporting, on all
  history. It reported zero findings.
- Downloaded and inspected the assets of all five releases: `v0.3.0`, `v0.4.0`,
  `android-v1.0.0`, `android-v1.0.1`, and their source/validation/DFU ZIPs and APKs.
  Expanded archive contents were scanned separately; zero Gitleaks findings.
- Retrieved the supplied enclosure ZIP from authenticated Drive and verified its
  SHA-256 against the existing local package before importing it. Scanned its
  extracted source, documentation, geometry and references; zero findings.
- Checked reachable historical filenames and extracted artifacts for credential
  files, Android signing keystores/password files, and private-key markers. None
  were found in the inspected material.
- Inspected EXIF/XMP location fields in eight user images and four validation
  screenshots. No GPS metadata was found. The visible personal content remains.

The Android signing key and password reside outside the repository, and no copies
were found in source archives, APK contents or other inspected releases. The
public certificate carried by an APK is expected and is not the private signing
key. Build scripts reference signing environment variables; those variable names
and local signing-file locations are not secret values.

## Information that would become public

| Finding | Where | Assessment |
| --- | --- | --- |
| Real name and personal email | Existing Git author and committer metadata | Identity/contact exposure. Changing future Git configuration does not alter old commits. |
| Pod BLE address | `recordings/*/session.json`, validation JSON/JSONL, and older release archives | A device identifier, not an authentication credential. Consider anonymizing it if you want the hardware less identifiable. |
| Computer username and absolute paths | Build instructions and several validation reports, including older release source/report archives | Reveals local account name and directory structure. No private file contents are exposed by the path alone. |
| Workout timestamps and metrics | Recordings, reference annotations, and Strava / Zwift screenshots | Personal activity data: cadence, pace, heart rate, time and distance. Keep only if you intend to share them. |
| Personal photographs | `docs/images/` | Shows legs/shoes and the desk/workspace. No GPS metadata was detected; visible content can still be identifying. |
| Drive file IDs and links | READMEs, Android validation reports, and some release metadata | Links to the APK/design files you intentionally supplied. They are not OAuth tokens; access follows Drive sharing settings. |

The author identity is not copied into this report as a new email listing; it is
already visible in `git log`. Raw scan reports contain no secret findings and were
kept outside the repository.

## Before publication

If those personal details are acceptable to you, this audit found no credential
issue that requires rotating a token or signing key. If any should remain private,
remove them from **history/tags and downloadable releases**, not only the latest
working files. Old source/validation ZIPs still contain device IDs and paths.
No history rewriting, image editing, release replacement or data deletion was
performed during this audit.

The original software is now MIT-licensed, as requested by the owner. The
imported CAD package has no licensing notice and includes an unchanged Seeed
board-reference STEP file. That reference and STL/STEP assets are outside the
software MIT grant. Its separate terms still apply to redistribution; the
software license does not change the contents or terms of the original ZIP.
The Gradle wrapper's existing upstream notices must also be retained.

Making a repository public is separate from granting an open-source license:
[GitHub's licensing guide](https://docs.github.com/en/repositories/managing-your-repositorys-settings-and-features/customizing-your-repository/licensing-a-repository)
explains the distinction. For cleanup, use
[GitHub's guidance on removing sensitive data](https://docs.github.com/en/authentication/keeping-your-account-and-data-secure/removing-sensitive-data-from-a-repository).

## Limits

Secret scanners can miss custom/encoded secrets, and this is not a guarantee that
every possible sensitive value is absent. Checks covered available repository
refs, uploaded release assets, supplied design files and visible images; they did
not review other private Drive files, unrelated repositories, or firmware/app
security vulnerabilities. This report records evidence at the audit date.

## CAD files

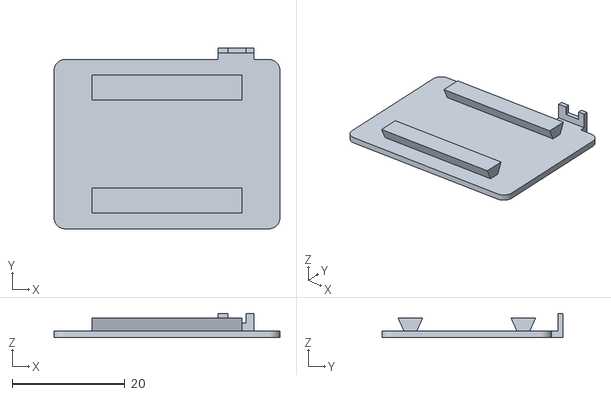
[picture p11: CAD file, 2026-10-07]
enclosure/low-profile-v5/glue-on-adapter.stl
40.0 x 32.0 x 4.30

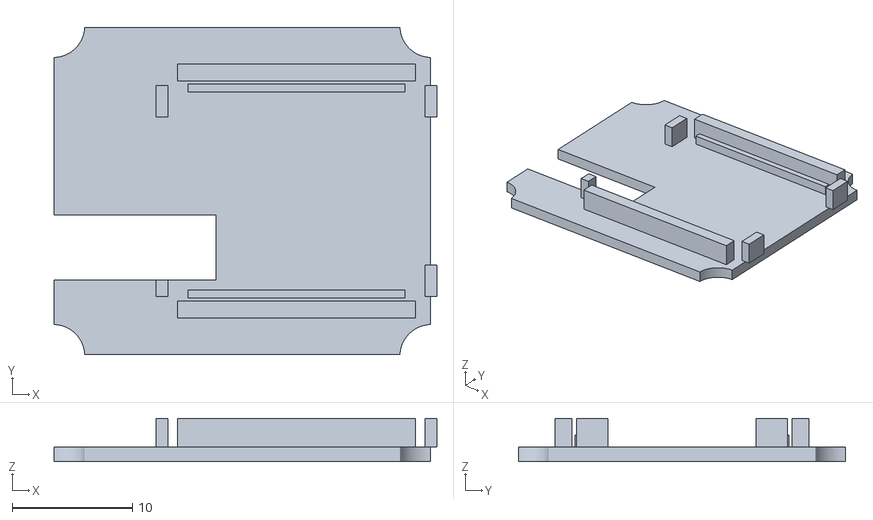
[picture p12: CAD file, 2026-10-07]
enclosure/low-profile-v5/references/proven-board-carrier.stl
31.8 x 27.2 x 3.60

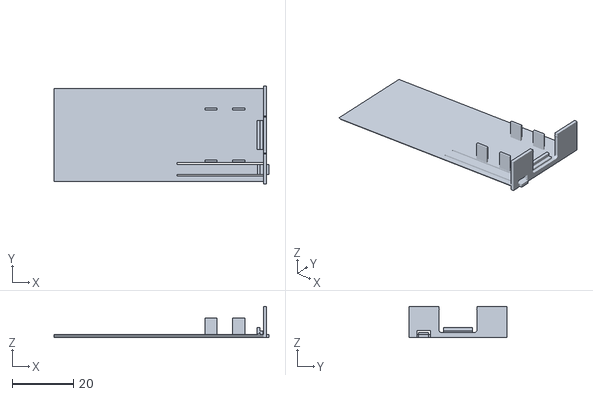
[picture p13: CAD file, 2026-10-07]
enclosure/low-profile-v5/sliding-cover.stl
70.1 x 32.0 x 10.2

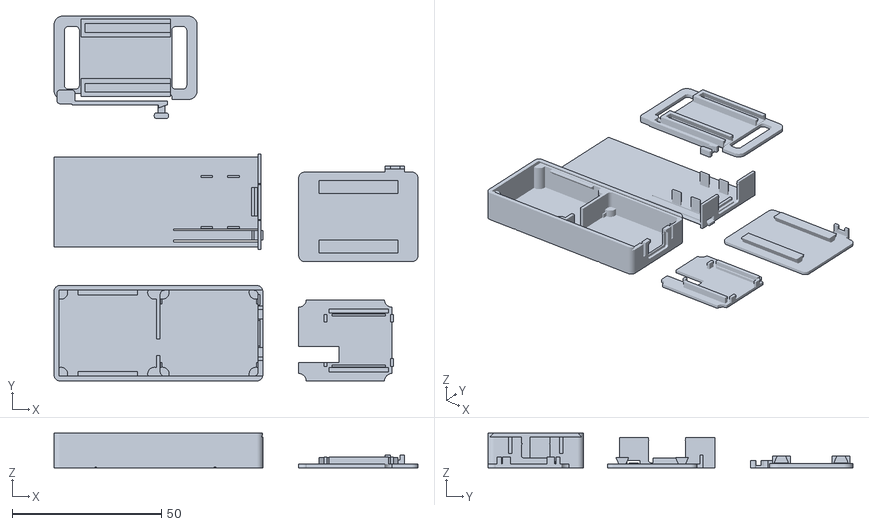
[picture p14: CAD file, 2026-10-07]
enclosure/low-profile-v5/low-profile-v5-print-plate.stl
122.0 x 122.3 x 11.6

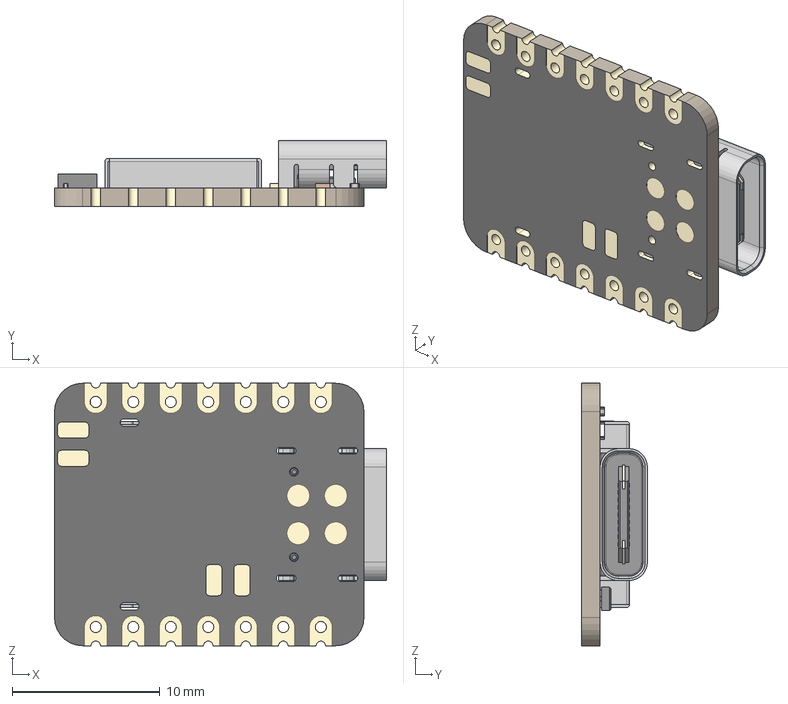
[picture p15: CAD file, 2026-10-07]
enclosure/low-profile-v5/references/sense-official-XIAO-nRF52840 v15.step
22.5 x 4.46 x 17.8 mm
BOSS-EXTRUDE14_8_
BOSS-EXTRUDE7_4_
BOSS-EXTRUDE7_3_
BOSS-EXTRUDE14_4_
BOSS-EXTRUDE14_2_
BOSS-EXTRUDE14_11_
BOSS-EXTRUDE7_7_
BOSS-EXTRUDE14_9_
BOSS-EXTRUDE14_3_
BOSS-EXTRUDE14_7_
MIRROR2
BOSS-EXTRUDE14_5_
BOSS-EXTRUDE14_12_
BOSS-EXTRUDE7_8_
BOSS-EXTRUDE7_1_
BOSS-EXTRUDE14_10_
BOSS-EXTRUDE7_9_
BOSS-EXTRUDE14_6_
BOSS-EXTRUDE14_1_
BOSS-EXTRUDE7_6_
BOSS-EXTRUDE7_2_
CUT-EXTRUDE5
BOSS-EXTRUDE7_5_
Shield
Pins
CAP x 2
ANT1
Silkscreen
CAP 3
LED
USR
2 v1

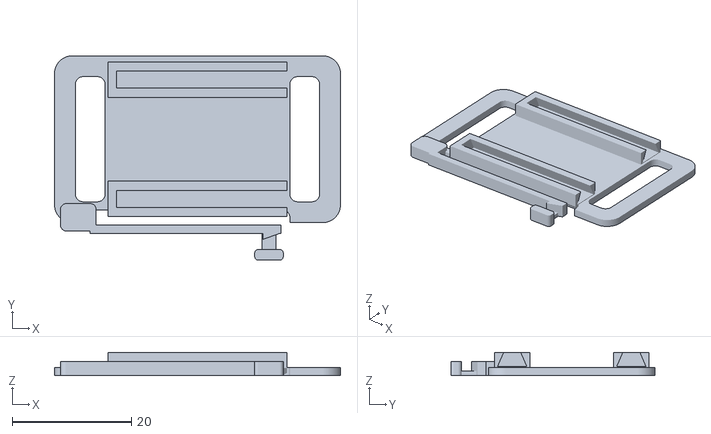
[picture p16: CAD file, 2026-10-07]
enclosure/low-profile-v5/references/proven-lace-base.stl
48.0 x 34.3 x 3.90

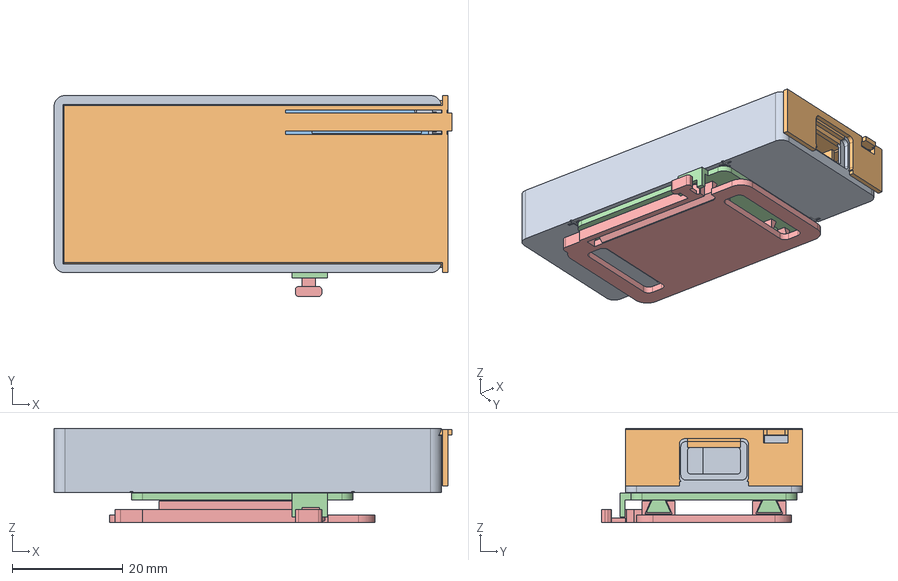
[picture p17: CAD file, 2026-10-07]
enclosure/low-profile-v5/low-profile-v5.step
71.9 x 36.3 x 17.0 mm

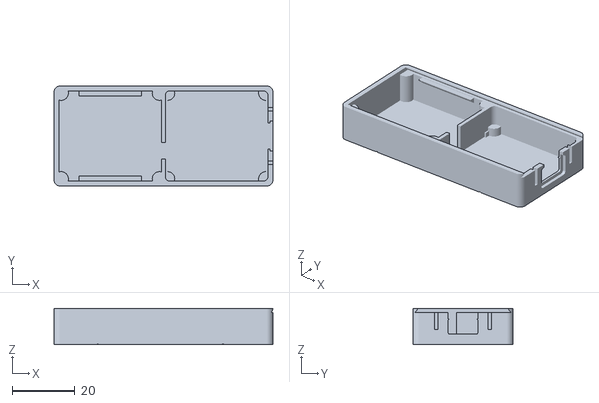
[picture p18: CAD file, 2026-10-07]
enclosure/low-profile-v5/body.stl
70.0 x 32.0 x 11.6

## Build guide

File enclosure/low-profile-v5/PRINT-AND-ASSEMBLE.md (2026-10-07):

# V5: 11.6 mm low-profile electronics housing

Housing: **70 × 32 × 11.6 mm**, down from 13.4 mm in v4.
Complete assembly with the unchanged glue-on dock: approximately
**72 × 36 × 17.0 mm**, down from 18.8 mm.

## Height budget

| Item | Height |
|---|---:|
| Floor | 1.20 mm |
| Thin battery mounting tape | 0.20 mm |
| Measured battery | 8.66 mm |
| Gap above the battery | 0.34 mm |
| Cover | 1.00 mm |
| Small outer rim allowance | 0.20 mm |
| Total housing | **11.60 mm** |

The flush dovetail lid rails fit within this height; v4's raised rail roofs are
removed. The side walls remain sturdy, while the floor and cover are thinner.
This is close to the practical lower limit for this battery. A substantially
lower housing would need a thinner battery, reduced clearance, or weaker skins.

## Parts retained

The existing fitted board tray, glue-on adapter and shoe base STLs are
byte-for-byte unchanged. All battery/PCB X–Y fit dimensions and the open wire
routes are retained. The battery and board/tray sit 0.4 mm lower because the
floor is thinner. Only the housing and sliding-cover designs change.

Keep the existing 0.2 mm tape allowance under the battery; do not add a thick
foam pad. The battery clearance above is only 0.34 mm, so check the printed
roof fit before closing and do not use the cover to compress the pouch cell.

## Printing

The same files are designed for PLA and PETG, with the flat print orientations
already saved. Start with a calibrated profile, 0.2 mm layers, a 0.4 mm nozzle,
and four walls. The floor is six 0.2 mm layers, and the cover is five layers.
The thinner cover is less stiff than v4, but still restrained along both rails.

- Housing: full flat bottom on the bed, electronics bays up.
- Cover: broad outer face on the bed; its tapered flanges grow at about
  42 degrees from vertical, and its pads/skirt grow upward.
- Glue adapter: flat glue face on the bed.
- Shoe base: bottom on the bed, sloped female dock channels upward.
- Tray: reuse your existing fitted part, or print the unchanged file flat.

Designed for supports off, with self-supporting rail slopes and no large bridge
across the outer USB boot window. Inspect the slicer layer preview; printer
settings may still need tuning for short local bridges and thin features.
Do not fuse the five separate parts in `low-profile-v5-print-plate.stl`.

## Assembly and use

Dry-fit the adapter and shoe base first. CA-glue the adapter's broad flat face
to the housing underside, aligning it with the four registration ticks. Its
catch faces the USB end and the side carrying the shoe base's release button.
Keep glue out of the moving rails/catch, and follow the adhesive's surface
preparation and cure instructions. Test the cured joint before installing
the electronics. Do not glue the shoe base to the adapter.

Place the permanently connected battery and board/tray in their separate bays,
with the battery's taped/wire end facing the board. Lay the leads in the
5.4 mm top-open gate and existing tray notch. Keep slack out of the lid rails
and hold-down pads; no connector needs to be disconnected or threaded through
a closed hole.

Slide the cover in from the USB end toward the battery end until it clicks.
Lift the small front tab about 0.7 mm to release and slide the cover out. If
the PCB has vertical play, use thin soft nonconductive tape only at the PCB-edge
hold-down pads. The cover should close without squeezing the battery.

Install the shoe base on the laces once. For charging, press its side tab inward
about 1.1 mm, slide the whole pod toward the USB end about 30 mm, and lift it
away. The shoe base stays attached. Charge with the cover closed and slide the
pod back until it clicks. No screws or hinge pins are required.

## Verification and limits

All five files have valid connected/watertight geometry and quantified flat bed
faces. CAD checks pass for the measured battery, official Sense board,
top-loading assembly, cover motion, released docking motion, and both catches
blocking withdrawal when latched. The nominal cover-arm beam strain estimate
is approximately 0.13%; the unchanged dock-arm estimate is 0.24%.

These are model checks, not physical PLA/PETG fatigue, printer or CA-bond tests.
Test fit, repeated release and attachment retention before running. The USB
opening is not waterproof. Editable CAD and the actual-height validation report
are included in the package.

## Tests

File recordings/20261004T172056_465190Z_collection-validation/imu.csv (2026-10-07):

sequence | device_us | elapsed_us | received_utc | received_monotonic_ns | gx_raw | gy_raw | gz_raw | ax_raw | ay_raw | az_raw | gx_dps | gy_dps | gz_dps | ax_g | ay_g | az_g
8529 | 81649414 | 0 | 2026-10-04T17:21:02.466346+00:00 | 87482487770507 | 63 | -70 | -16 | -1308 | -2414 | 3227 | 2.205 | -2.45 | -0.56 | -0.319152 | -0.589016 | 0.787388
8530 | 81659179 | 9765 | 2026-10-04T17:21:02.467019+00:00 | 87482488423335 | 66 | -65 | -16 | -1308 | -2416 | 3228 | 2.31 | -2.275 | -0.56 | -0.319152 | -0.589504 | 0.787632
8531 | 81669921 | 20507 | 2026-10-04T17:21:02.468997+00:00 | 87482490413105 | 69 | -62 | -16 | -1309 | -2414 | 3227 | 2.415 | -2.17 | -0.56 | -0.319396 | -0.589016 | 0.787388
8532 | 81679687 | 30273 | 2026-10-04T17:21:02.469838+00:00 | 87482491251246 | 67 | -65 | -16 | -1308 | -2415 | 3230 | 2.345 | -2.275 | -0.56 | -0.319152 | -0.58926 | 0.78812
8533 | 81689453 | 40039 | 2026-10-04T17:21:02.470512+00:00 | 87482491915579 | 66 | -67 | -16 | -1304 | -2416 | 3230 | 2.31 | -2.345 | -0.56 | -0.318176 | -0.589504 | 0.78812
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

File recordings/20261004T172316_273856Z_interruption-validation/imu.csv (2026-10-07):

sequence | device_us | elapsed_us | received_utc | received_monotonic_ns | gx_raw | gy_raw | gz_raw | ax_raw | ay_raw | az_raw | gx_dps | gy_dps | gz_dps | ax_g | ay_g | az_g
22895 | 218458984 | 0 | 2026-10-04T17:23:19.268901+00:00 | 87619290306605 | 62 | -66 | -20 | -1305 | -2415 | 3225 | 2.17 | -2.31 | -0.7 | -0.31842 | -0.58926 | 0.7869
22896 | 218469726 | 10742 | 2026-10-04T17:23:19.269317+00:00 | 87619290716822 | 62 | -68 | -19 | -1309 | -2419 | 3220 | 2.17 | -2.38 | -0.665 | -0.319396 | -0.590236 | 0.78568
22897 | 218479492 | 20508 | 2026-10-04T17:23:19.269784+00:00 | 87619291178198 | 66 | -69 | -16 | -1305 | -2420 | 3225 | 2.31 | -2.415 | -0.56 | -0.31842 | -0.59048 | 0.7869
22898 | 218489257 | 30273 | 2026-10-04T17:23:19.271336+00:00 | 87619292731892 | 70 | -67 | -13 | -1311 | -2425 | 3227 | 2.45 | -2.345 | -0.455 | -0.319884 | -0.5917 | 0.787388
22899 | 218499023 | 40039 | 2026-10-04T17:23:19.313485+00:00 | 87619334892308 | 69 | -65 | -14 | -1304 | -2418 | 3228 | 2.415 | -2.275 | -0.49 | -0.318176 | -0.589992 | 0.787632
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

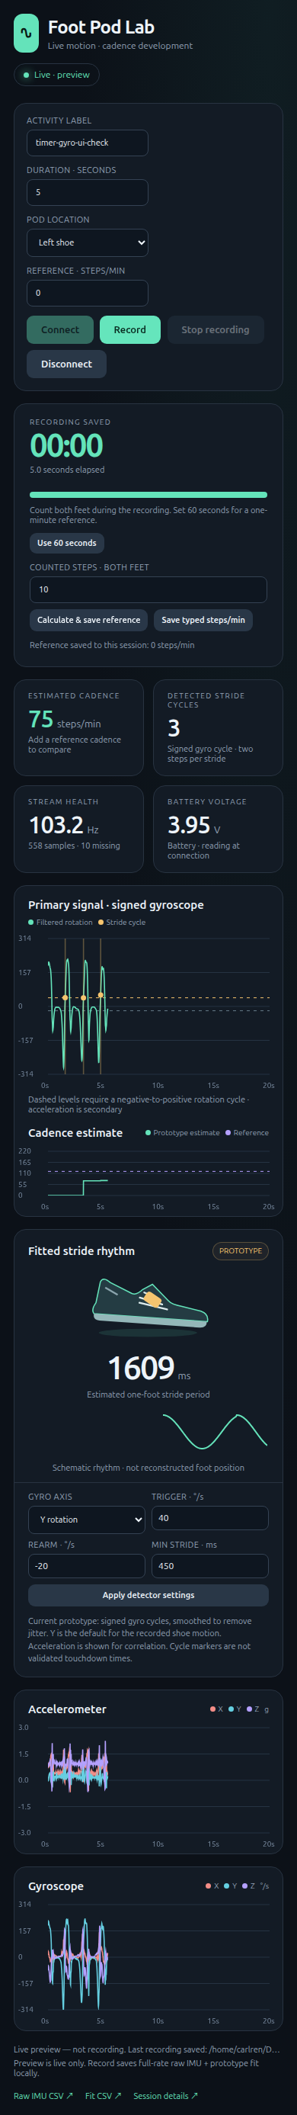
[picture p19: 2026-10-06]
validation/dashboard-mobile.png

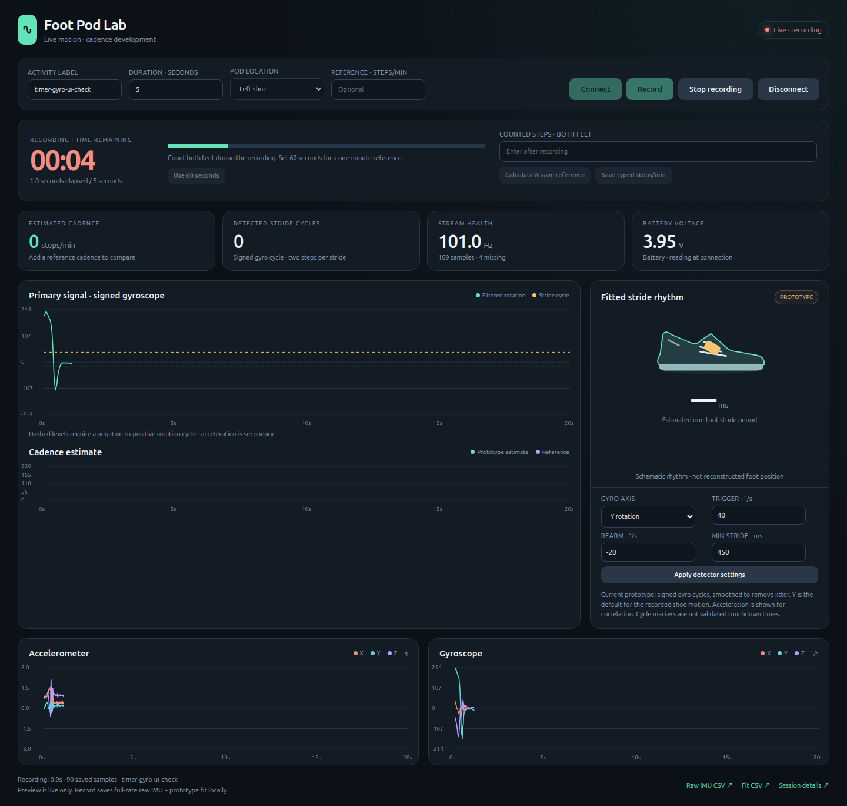
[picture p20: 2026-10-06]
validation/dashboard-countdown.png

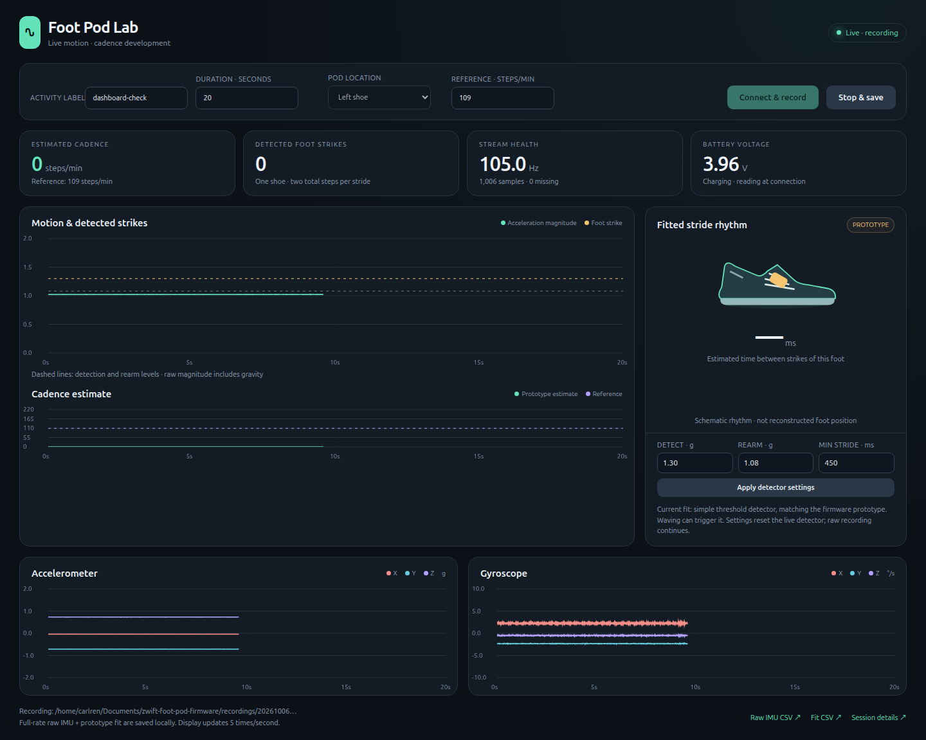
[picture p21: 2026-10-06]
validation/dashboard-live.png

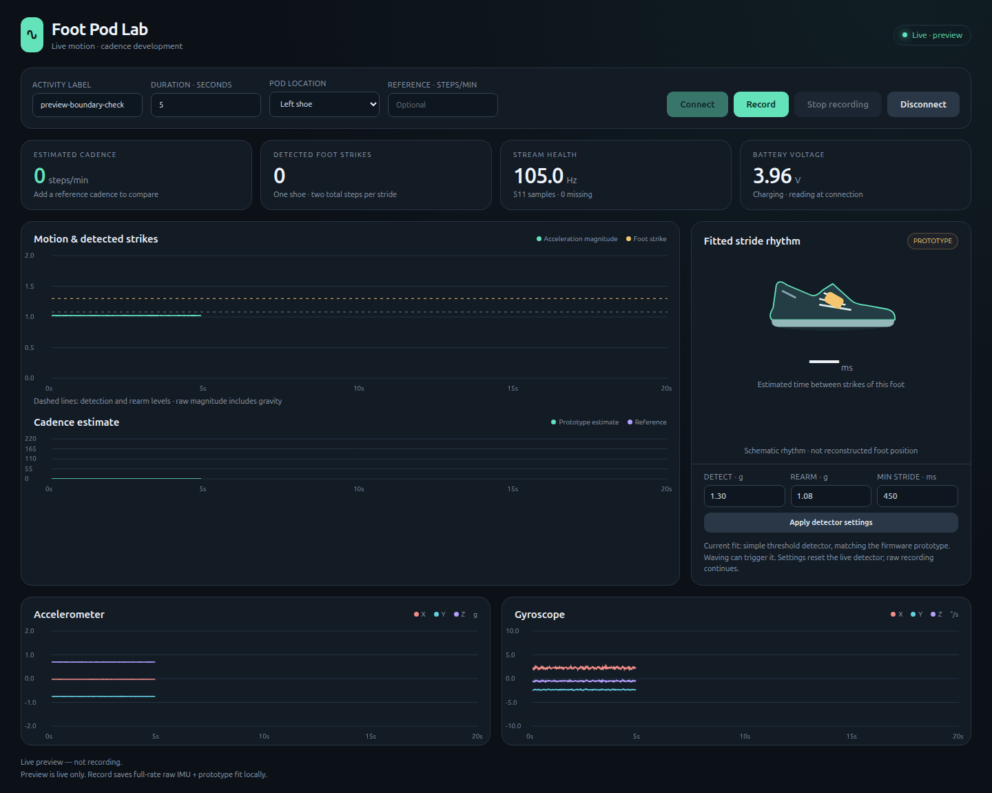
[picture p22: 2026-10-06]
validation/dashboard-preview.png

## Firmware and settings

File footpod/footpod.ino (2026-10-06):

#include <Adafruit_TinyUSB.h>
#include <bluefruit.h>
#include <nrfx_twim.h>
#include <hal/nrf_gpio.h>
#include <math.h>
#include "cadence.h"
#include "companion.h"

// Seeed nRF52 Boards 1.1.13; XIAO nRF52840 Sense (original, not Plus).
constexpr uint8_t IMU_ADDRESS = 0x6A;
constexpr float STEP_LENGTH_M = 0.70f; // Mock speed only; calibrate later.
constexpr float BATTERY_DIVIDER = 1510.0f / 510.0f; // R16=1 MΩ, R17=510 kΩ.

BLEService rsc(0x1814);
BLECharacteristic measurement(0x2A53), feature(0x2A54), location(0x2A5D);
BLEDis deviceInfo;
BLEService collection("e85b0001-6d10-4a22-90c5-c813f72b1357");
BLECharacteristic imuData("e85b0002-6d10-4a22-90c5-c813f72b1357");
BLECharacteristic collectionControl("e85b0003-6d10-4a22-90c5-c813f72b1357");
BLECharacteristic collectionStatus("e85b0004-6d10-4a22-90c5-c813f72b1357");
BLECharacteristic batteryVoltage("e85b0005-6d10-4a22-90c5-c813f72b1357");
uint16_t batteryAdc = 0, batteryMv = 0;
bool batteryCharging = false, usbPower = false;
BLEService batteryService(0x180F);
BLECharacteristic batteryLevel(0x2A19);
uint8_t batteryPct = 0;
PodClients clients;
uint8_t cadencePacket[4] = {};
bool imuReady = false;
GyroCadence gyroCadence;
uint8_t whoAmI = 0, fixedCadence = 0;
uint32_t samples = 0, imuErrors = 0;
uint32_t notifications = 0, notifyErrors = 0, lastSample = 0;
float ax = 0, ay = 0, az = 0, gx = 0, gy = 0, gz = 0;
char command[40];
uint8_t commandLength = 0;
bool commandOverflow = false;
char logBuffer[512];
uint16_t logLength = 0, logOffset = 0;
const nrfx_twim_t imuBus = NRFX_TWIM_INSTANCE(1);
volatile bool transferDone = false, transferOk = false;

void imuTransferDone(nrfx_twim_evt_t const* event, void*) {
  transferOk = event->type == NRFX_TWIM_EVT_DONE;
  transferDone = true;
}

bool transfer(nrfx_twim_xfer_desc_t const& request) {
  transferDone = false; transferOk = false;
  if (nrfx_twim_xfer(&imuBus, &request, 0) != NRFX_SUCCESS) return false;
  uint32_t started = millis();
  while (!transferDone && uint32_t(millis() - started) < 50) delay(1);
  if (!transferDone) { nrfx_twim_disable(&imuBus); imuReady = false; }
  return transferDone && transferOk;
}

bool readRegisters(uint8_t reg, uint8_t* data, uint8_t length) {
  nrfx_twim_xfer_desc_t request = NRFX_TWIM_XFER_DESC_TXRX(IMU_ADDRESS, &reg, 1, data, length);
  return transfer(request);
}

bool writeRegister(uint8_t reg, uint8_t value) {
  uint8_t data[] = {reg, value};
  nrfx_twim_xfer_desc_t request = NRFX_TWIM_XFER_DESC_TX(IMU_ADDRESS, data, 2);
  return transfer(request);
}

bool startImu() {
  pinMode(PIN_LSM6DS3TR_C_POWER, OUTPUT);
  // Seeed's IMU library requires high drive on the sensor supply pin, P1.08.
  nrf_gpio_cfg(g_ADigitalPinMap[PIN_LSM6DS3TR_C_POWER], NRF_GPIO_PIN_DIR_OUTPUT,
               NRF_GPIO_PIN_INPUT_DISCONNECT, NRF_GPIO_PIN_NOPULL,
               NRF_GPIO_PIN_H0H1, NRF_GPIO_PIN_NOSENSE);
  digitalWrite(PIN_LSM6DS3TR_C_POWER, HIGH);
  delay(20);
  // The bundled Nordic driver supports asynchronous reads and a bounded timeout.
  nrfx_twim_config_t busConfig = NRFX_TWIM_DEFAULT_CONFIG(27, 7);
  busConfig.frequency = NRF_TWIM_FREQ_400K;
  if (nrfx_twim_init(&imuBus, &busConfig, imuTransferDone, nullptr) != NRFX_SUCCESS) return false;
  nrfx_twim_enable(&imuBus);
  if (!readRegisters(0x0F, &whoAmI, 1) || whoAmI != 0x6A) return false;
  // CTRL3_C: block update + address increment. 104 Hz, ±8 g, ±1000 dps.
  if (!writeRegister(0x12, 0x44) || !writeRegister(0x10, 0x4C) ||
      !writeRegister(0x11, 0x48)) return false;
  uint8_t config[3];
  return readRegisters(0x10, config, 3) && config[0] == 0x4C &&
         config[1] == 0x48 && config[2] == 0x44;
}

int16_t signedWord(const uint8_t* data) {
  return static_cast<int16_t>(uint16_t(data[0]) | (uint16_t(data[1]) << 8));
}

void resetEstimator() {
  gyroCadence.reset();
}

void writeWord(uint8_t* out, uint32_t value) {
  for (uint8_t i = 0; i < 4; ++i) out[i] = uint8_t(value >> (8 * i));
}

// Native HVX is nonblocking. A busy phone queue never stalls sensor sampling
// or the separate Zwift connection. All notification paths use the same API.
uint32_t notify(uint16_t handle, BLECharacteristic& characteristic,
                const uint8_t* data, uint16_t length) {
  ble_gatts_hvx_params_t request = {};
  request.handle = characteristic.handles().value_handle;
  request.type = BLE_GATT_HVX_NOTIFICATION;
  request.p_len = &length; request.p_data = data;
  return sd_ble_gatts_hvx(handle, &request);
}

void streamImu(const uint8_t* raw, uint32_t sample_us) {
  uint8_t packet[20];
  writeWord(packet, samples); writeWord(packet + 4, sample_us);
  memcpy(packet + 8, raw, 12);
  for (auto& peer : clients.slots) {
    if (peer.handle == 0xffff || !peer.collecting || !imuData.notifyEnabled(peer.handle)) continue;
    if (notify(peer.handle, imuData, packet, sizeof(packet)) == NRF_SUCCESS) ++peer.sent;
    else ++peer.dropped;
  }
}

void readCollectionStatus(uint16_t handle, BLECharacteristic*, ble_gatts_evt_read_t* request) {
  auto* peer = clients.find(handle);
  // Same v1 wire format; collection state and counters belong to the reader.
  uint8_t data[16] = {1, uint8_t((imuReady ? 1 : 0) |
    (peer && peer->collecting ? 2 : 0) | (imuData.notifyEnabled(handle) ? 4 : 0)), whoAmI, 0};
  writeWord(data + 4, peer ? peer->sent : 0);
  writeWord(data + 8, peer ? peer->dropped : 0); writeWord(data + 12, imuErrors);
  ble_gatts_rw_authorize_reply_params_t reply = {};
  reply.type = BLE_GATTS_AUTHORIZE_TYPE_READ;
  reply.params.read.gatt_status = request->offset <= sizeof(data) ?
      BLE_GATT_STATUS_SUCCESS : BLE_GATT_STATUS_ATTERR_INVALID_OFFSET;
  reply.params.read.update = 1;
  reply.params.read.offset = 0; reply.params.read.len = sizeof(data);
  reply.params.read.p_data = data;
  sd_ble_gatts_rw_authorize_reply(handle, &reply);
}

void collectionCommand(uint16_t handle, BLECharacteristic*, uint8_t* data, uint16_t length) {
  auto* peer = clients.find(handle);
  if (peer && length == 1 && data[0] <= 1) peer->collecting = data[0] == 1;
}

void collectionConnected(uint16_t handle) { clients.connect(handle); }
void collectionDisconnected(uint16_t handle, uint8_t) { clients.disconnect(handle); }

void readBattery() {
  batteryAdc = analogRead(PIN_VBAT);
  batteryMv = uint16_t(lroundf(batteryAdc * (3000.0f / 4096.0f) * BATTERY_DIVIDER));
  batteryCharging = digitalRead(23) == LOW; // P0.17, active-low charger output.
  usbPower = (NRF_POWER->USBREGSTATUS & POWER_USBREGSTATUS_VBUSDETECT_Msk) != 0;
  uint8_t data[6] = {uint8_t(batteryMv), uint8_t(batteryMv >> 8),
                    uint8_t(batteryAdc), uint8_t(batteryAdc >> 8),
                    uint8_t(batteryCharging), uint8_t(usbPower)};
  batteryVoltage.write(data, sizeof(data));
  uint8_t previous = batteryPct;
  batteryPct = batteryPercent(batteryMv);
  batteryLevel.write8(batteryPct);
  if (previous != batteryPct) for (auto& peer : clients.slots)
    if (peer.handle != 0xffff && batteryLevel.notifyEnabled(peer.handle))
      notify(peer.handle, batteryLevel, &batteryPct, 1);
}

void sampleImu(uint32_t now) {
  uint8_t status, raw[12];
  if (!readRegisters(0x1E, &status, 1)) { ++imuErrors; return; }
  if ((status & 3) != 3) return; // Only consume fresh accel AND gyro data.
  if (!readRegisters(0x22, raw, sizeof(raw))) { ++imuErrors; return; }
  gx = signedWord(raw) * 0.035f;
  gy = signedWord(raw + 2) * 0.035f;
  gz = signedWord(raw + 4) * 0.035f;
  ax = signedWord(raw + 6) * 0.000244f;
  ay = signedWord(raw + 8) * 0.000244f;
  az = signedWord(raw + 10) * 0.000244f;
  ++samples; lastSample = now;
  uint32_t sample_us = micros();
  gyroCadence.update(gy, sample_us);
  streamImu(raw, sample_us);
}

uint8_t cadence(uint32_t now) {
  if (fixedCadence) return fixedCadence;
  if (!imuReady || !samples || uint32_t(now - lastSample) > 250) return 0;
  return gyroCadence.cadence(micros());
}

void publish(uint32_t now) {
  uint8_t spm = cadence(now);
  // RSC: flags, speed (m/s * 256, little endian), cadence (steps/min).
  // Mandatory speed uses a placeholder step length; no optional features claimed.
  uint16_t speed = uint16_t(lroundf(spm * STEP_LENGTH_M / 60.0f * 256.0f));
  uint8_t packet[4] = {0, uint8_t(speed), uint8_t(speed >> 8), spm};
  memcpy(cadencePacket, packet, sizeof(packet));
  measurement.write(packet, sizeof(packet));
  for (auto& peer : clients.slots)
    if (peer.handle != 0xffff) peer.cadencePending = true;
}

void flushCadence() {
  for (auto& peer : clients.slots) {
    if (peer.handle == 0xffff || !peer.cadencePending) continue;
    if (!measurement.notifyEnabled(peer.handle)) { peer.cadencePending = false; continue; }
    uint32_t result = notify(peer.handle, measurement, cadencePacket, sizeof(cadencePacket));
    // Give cadence priority over raw samples; retry queue congestion next loop.
    if (result == NRF_ERROR_RESOURCES) continue;
    peer.cadencePending = false;
    if (result == NRF_SUCCESS) ++notifications; else ++notifyErrors;
  }
}

bool cadenceSubscribed() {
  for (auto& peer : clients.slots)
    if (peer.handle != 0xffff && measurement.notifyEnabled(peer.handle)) return true;
  return false;
}

void serialCommands() {
  while (Serial.available()) {
    char c = Serial.read();
    if (c == '\r') continue;
    if (c != '\n') {
      if (commandLength < sizeof(command) - 1) command[commandLength++] = c;
      else commandOverflow = true;
      continue;
    }
    if (commandOverflow) { commandLength = 0; commandOverflow = false; continue; }
    command[commandLength] = 0;
    unsigned value; char extra;
    if (!strcmp(command, "imu")) { fixedCadence = 0; resetEstimator(); }
    else if (sscanf(command, "mock %3u %c", &value, &extra) == 1 && value >= 1 && value <= 255)
      fixedCadence = value;
    else if (!strcmp(command, "stop")) { fixedCadence = 0; resetEstimator(); }
    else if (Serial && Serial.availableForWrite() >= 40)
      Serial.println("Commands: imu | mock 1..255 | stop");
    commandLength = 0;
  }
}

void telemetry(uint32_t now) {
  if (!Serial || logOffset < logLength) return;
  int length = snprintf(logBuffer, sizeof(logBuffer),
    "{\"ms\":%lu,\"mode\":\"%s\",\"imu_ok\":%s,\"who\":%u,\"samples\":%lu,"
    "\"imu_errors\":%lu,\"a_g\":[%.4f,%.4f,%.4f],\"gyro_dps\":[%.2f,%.2f,%.2f],"
    "\"strikes\":%lu,\"cadence_spm\":%u,\"connected\":%s,\"subscribed\":%s,"
    "\"notifications\":%lu,\"notify_errors\":%lu,\"battery_mv\":%u,"
    "\"battery_pct\":%u,\"connections\":%u,\"charging\":%s,\"usb_power\":%s}\n",
    (unsigned long)now, fixedCadence ? "mock" : "imu", imuReady ? "true" : "false",
    whoAmI, (unsigned long)samples, (unsigned long)imuErrors, ax, ay, az, gx, gy, gz,
    (unsigned long)gyroCadence.cycles, cadence(now), Bluefruit.connected() ? "true" : "false",
    cadenceSubscribed() ? "true" : "false", (unsigned long)notifications,
    (unsigned long)notifyErrors, batteryMv, batteryPct, Bluefruit.Periph.connected(), batteryCharging ? "true" : "false",
    usbPower ? "true" : "false");
  logLength = length > 0 && length < int(sizeof(logBuffer)) ? length : 0;
  logOffset = 0;
}

void flushTelemetry() {
  if (!Serial) { logLength = logOffset = 0; return; }
  // Never wait for USB: a client can hold DTR high without draining the port.
  int available = Serial.availableForWrite();
  if (available > 0 && logOffset < logLength) {
    size_t count = min(uint16_t(available), uint16_t(logLength - logOffset));
    logOffset += Serial.write(reinterpret_cast<uint8_t*>(logBuffer + logOffset), count);
  }
}

void setup() {
  // Keep the divider enabled (P0.14 LOW), including while USB charges the battery.
  digitalWrite(VBAT_ENABLE, LOW); pinMode(VBAT_ENABLE, OUTPUT);
  pinMode(PIN_VBAT, INPUT); pinMode(23, INPUT);
  analogReadResolution(12); analogReference(AR_INTERNAL_3_0);
  analogSampleTime(40); // Microseconds; high-impedance battery divider.
  analogOversampling(4);
  Serial.begin(115200); // Never wait for USB: standalone battery operation.
  // 20-byte packets need no MTU negotiation; buffer short radio scheduling bursts.
  Bluefruit.configPrphConn(23, 6, 64, 1);
  Bluefruit.begin(2, 0);
  imuReady = startImu();
  digitalWrite(LED_RED, imuReady ? HIGH : LOW);
  Bluefruit.autoConnLed(false);
  Bluefruit.setName("Carl Foot Pod");
  Bluefruit.setTxPower(4);
  Bluefruit.Periph.setConnInterval(12, 24); // 15–30 ms, enough for the 104 Hz stream.
  Bluefruit.Periph.setConnectCallback(collectionConnected);
  Bluefruit.Periph.setDisconnectCallback(collectionDisconnected);
  deviceInfo.setManufacturer("Carl");
  deviceInfo.setModel("XIAO nRF52840 Sense");
  deviceInfo.setSoftwareRev("0.4.0");
  deviceInfo.begin();
  rsc.begin();
  measurement.setProperties(CHR_PROPS_NOTIFY);
  measurement.setPermission(SECMODE_OPEN, SECMODE_NO_ACCESS);
  measurement.setFixedLen(4);
  measurement.begin();
  feature.setProperties(CHR_PROPS_READ);
  feature.setPermission(SECMODE_OPEN, SECMODE_NO_ACCESS);
  feature.setFixedLen(2); feature.begin(); feature.write16(0);
  location.setProperties(CHR_PROPS_READ);
  location.setPermission(SECMODE_OPEN, SECMODE_NO_ACCESS);
  location.setFixedLen(1); location.begin(); location.write8(6); // Left foot.
  publish(millis());
  collection.begin();
  imuData.setProperties(CHR_PROPS_NOTIFY);
  imuData.setPermission(SECMODE_OPEN, SECMODE_NO_ACCESS);
  imuData.setFixedLen(20); imuData.begin();
  collectionControl.setProperties(CHR_PROPS_WRITE);
  collectionControl.setPermission(SECMODE_NO_ACCESS, SECMODE_OPEN);
  collectionControl.setFixedLen(1);
  collectionControl.setWriteCallback(collectionCommand, false);
  collectionControl.begin();
  collectionStatus.setProperties(CHR_PROPS_READ);
  collectionStatus.setPermission(SECMODE_OPEN, SECMODE_NO_ACCESS);
  collectionStatus.setFixedLen(16);
  collectionStatus.setReadAuthorizeCallback(readCollectionStatus, false);
  collectionStatus.begin();
  batteryVoltage.setProperties(CHR_PROPS_READ);
  batteryVoltage.setPermission(SECMODE_OPEN, SECMODE_NO_ACCESS);
  batteryVoltage.setFixedLen(6); batteryVoltage.begin();
  batteryService.begin();
  batteryLevel.setProperties(CHR_PROPS_READ | CHR_PROPS_NOTIFY);
  batteryLevel.setPermission(SECMODE_OPEN, SECMODE_NO_ACCESS);
  batteryLevel.setFixedLen(1);
  batteryLevel.setUserDescriptor("Battery level (estimated)");
  batteryLevel.begin();
  readBattery();
  Bluefruit.Advertising.addFlags(BLE_GAP_ADV_FLAGS_LE_ONLY_GENERAL_DISC_MODE);
  Bluefruit.Advertising.addAppearance(0x0441); // Running/walking sensor, in shoe.
  Bluefruit.Advertising.addService(rsc);
  Bluefruit.Advertising.addName();
  Bluefruit.ScanResponse.addService(collection);
  Bluefruit.Advertising.restartOnDisconnect(true);
  Bluefruit.Advertising.setInterval(160, 244); // 100–152.5 ms; leave airtime for both links.
  Bluefruit.Advertising.setFastTimeout(30);
  Bluefruit.Advertising.start(0); // Continue advertising at rest, without USB.
}

void loop() {
  static uint32_t sampleTimer = 0, publishTimer = 0, logTimer = 0, advertisingTimer = 0;
  uint32_t now = millis();
  serialCommands();
  flushCadence();
  if (imuReady && uint32_t(now - sampleTimer) >= 5) {
    sampleTimer = now; sampleImu(now);
  }
  if (uint32_t(now - publishTimer) >= 1000) {
    publishTimer = now; readBattery(); publish(now);
  }
  if (uint32_t(now - logTimer) >= 200) {
    logTimer = now; telemetry(now);
  }
  if (uint32_t(now - advertisingTimer) >= 200) {
    advertisingTimer = now;
    // Bluefruit's automatic restart only handles the last client disconnect.
    if (Bluefruit.Periph.connected() < 2 && !Bluefruit.Advertising.isRunning())
      Bluefruit.Advertising.start(0);
  }
  flushTelemetry();
  delay(1);
}

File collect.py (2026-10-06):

"""Record the battery-powered foot pod's six-axis IMU over Bluetooth to CSV."""
import argparse
import asyncio
import csv
from datetime import datetime, timezone
import json
from pathlib import Path
import re
import struct
import time

from bleak import BleakClient, BleakScanner

ROOT = Path(__file__).resolve().parent
SERVICE, DATA, CONTROL, STATUS = (
    f"e85b000{i}-6d10-4a22-90c5-c813f72b1357" for i in range(1, 5)
)
PACKET = struct.Struct("<II6h") # sequence, device us, gyro XYZ, accel XYZ
ACCEL_G_PER_LSB, GYRO_DPS_PER_LSB = 0.000244, 0.035


def decode_status(payload):
    if len(payload) != 16:
        raise ValueError("Unexpected IMU status length")
    version, flags, who, reserved, sent, dropped, errors = struct.unpack("<BBBBIII", payload)
    if version != 1 or reserved or flags & ~7:
        raise ValueError("Unsupported IMU stream protocol")
    return dict(version=version, imu_ok=bool(flags & 1), collecting=bool(flags & 2),
                subscribed=bool(flags & 4), who_am_i=who, sent=sent, dropped=dropped,
                imu_errors=errors)


def positive(value):
    number = float(value)
    if not 0 < number < float("inf"):
        raise argparse.ArgumentTypeError("Must be a finite positive number")
    return number


class PacketDecoder:
    """Shared timestamp/sequence validation for live preview and saved recordings."""
    def __init__(self):
        self.last_seq = self.last_us = None
        self.elapsed_us = self.missing = 0

    def decode(self, payload):
        if len(payload) != PACKET.size:
            raise ValueError(f"IMU packet must be 20 bytes; got {len(payload)}")
        seq, device_us, *raw = PACKET.unpack(payload)
        if self.last_seq is not None:
            increment = (seq - self.last_seq) & 0xFFFFFFFF
            interval = (device_us - self.last_us) & 0xFFFFFFFF
            if not 0 < increment < 0x80000000 or not 0 < interval < 3_000_000:
                raise ValueError("Duplicate/out-of-order data or device clock reset")
            self.missing += increment - 1
            self.elapsed_us += interval
        self.last_seq, self.last_us = seq, device_us
        return dict(sequence=seq, device_us=device_us, elapsed_us=self.elapsed_us,
                    time_s=self.elapsed_us / 1_000_000, raw=raw,
                    received_utc=datetime.now(timezone.utc).isoformat(), received_monotonic_ns=time.monotonic_ns(),
                    gyro=[round(v * GYRO_DPS_PER_LSB, 6) for v in raw[:3]],
                    accel=[round(v * ACCEL_G_PER_LSB, 6) for v in raw[3:]], missing=self.missing)


class Recording:
    """Open files only when the user actually starts recording."""
    def __init__(self, args, connection=None):
        stamp = datetime.now(timezone.utc).strftime("%Y%m%dT%H%M%S_%fZ")
        self.directory = ROOT / "recordings" / f"{stamp}_{args.label}"
        self.directory.mkdir(parents=True)
        self.metadata = dict(started_utc=datetime.now(timezone.utc).isoformat(), label=args.label,
            seconds_requested=args.seconds, foot=args.foot, reference_spm=args.reference_spm,
            speed_kph=args.speed_kph, protocol_version=1, nominal_hz=104,
            accel_g_per_lsb=ACCEL_G_PER_LSB, gyro_dps_per_lsb=GYRO_DPS_PER_LSB,
            accel_range_g=8, gyro_range_dps=1000, completed=False, samples=0, missing_packets=0,
            clipped_samples=0, timing_gaps_over_20ms=0, max_interval_us=0)
        self.metadata.update({k:v for k,v in (connection or {}).items()
                              if k in ('address','firmware','status_before','battery')})
        self.handle = (self.directory / 'imu.csv').open('x', newline='')
        self.writer = csv.writer(self.handle)
        self.writer.writerow(['sequence','device_us','elapsed_us','received_utc','received_monotonic_ns',
                             'gx_raw','gy_raw','gz_raw','ax_raw','ay_raw','az_raw',
                             'gx_dps','gy_dps','gz_dps','ax_g','ay_g','az_g'])
        self.first_time = self.first_seq = self.last_time = self.last_seq = None

    def append(self, sample):
        seq, t = sample['sequence'], sample['elapsed_us']
        if self.first_time is None:
            self.first_time, self.first_seq = t, seq
        if self.last_time is not None:
            interval = t - self.last_time
            self.metadata['missing_packets'] += ((seq-self.last_seq)&0xFFFFFFFF)-1
            self.metadata['timing_gaps_over_20ms'] += int(interval>20_000)
            self.metadata['max_interval_us'] = max(self.metadata['max_interval_us'],interval)
        elapsed = t-self.first_time
        self.writer.writerow([seq,sample['device_us'],elapsed,sample['received_utc'],sample['received_monotonic_ns'],
                              *sample['raw'],*sample['gyro'],*sample['accel']])
        self.metadata['samples'] += 1
        self.metadata['clipped_samples'] += int(any(v in (-32768,32767) for v in sample['raw']))
        self.last_time, self.last_seq = t,seq
        return elapsed/1_000_000

    def flush(self):
        self.handle.flush()

    def finish(self, error=None, stopped_by_user=False, connection=None):
        self.handle.close()
        self.metadata['completed'] = error is None and self.metadata['samples']>=2
        self.metadata['stopped_by_user'] = stopped_by_user
        if error is not None:
            self.metadata['error'] = type(error).__name__+': '+str(error)
        self.metadata.update({k:v for k,v in (connection or {}).items() if k=='status_after'})
        self.metadata['ended_utc'] = datetime.now(timezone.utc).isoformat()
        elapsed = (self.last_time-self.first_time) if self.last_time is not None else 0
        self.metadata['device_duration_s'] = elapsed/1_000_000
        if elapsed:
            self.metadata['received_hz'] = round((self.metadata['samples']-1)*1_000_000/elapsed,3)
            self.metadata['sampled_hz'] = round(((self.last_seq-self.first_seq)&0xFFFFFFFF)*1_000_000/elapsed,3)
        (self.directory/'session.json').write_text(json.dumps(self.metadata,indent=2)+'\n')
        return self.metadata
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

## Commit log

2026-10-04 Save Zwift foot pod firmware and Bluetooth IMU collector
2026-10-06 Expose battery voltage and charger status over Bluetooth
2026-10-06 Add live Bluetooth IMU dashboard with prototype cadence visualization
2026-10-06 Add countdown and reference counts with gyro-first cadence fitting
2026-10-06 Deploy validated gyro cadence detector to XIAO firmware 0.3.0
2026-10-06 Add concurrent Zwift and companion BLE connections with battery percentage
2026-10-06 Add signed Android foot pod companion with live IMU preview and recording
2026-10-07 Add dedicated foot pod battery bar to Android app 1.0.1
2026-10-07 Document foot pod with real hardware photos and app screenshots; preserve all recordings
    [fit.csv, gyro_fit.csv, imu.csv]
2026-10-07 Add mounting clip and walking desk photos to illustrated README
2026-10-07 Import verified V5 enclosure package and document public-release audit
    [board-carrier.stl, body.stl, glue-on-adapter.stl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]
2026-10-07 Add Amazon board purchase link and hardware parts list to README
